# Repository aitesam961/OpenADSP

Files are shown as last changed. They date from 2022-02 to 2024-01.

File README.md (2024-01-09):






<p align="center">
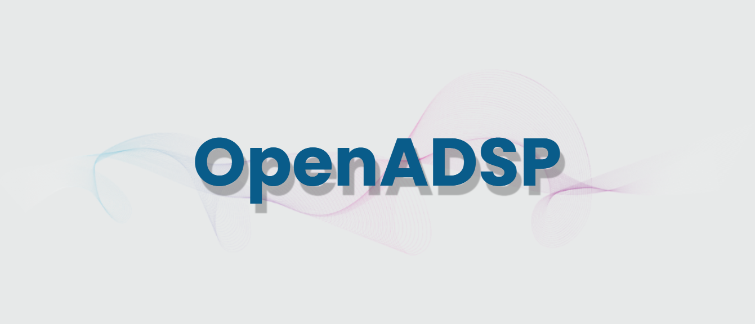
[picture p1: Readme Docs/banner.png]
  
</p>

> An Embedded solution for Digital Signal Processing Applications in Audio signal processing.

## Table of contents
* [Description](https://github.com/maitesam/OpenADSP/blob/main/README.md#Description)
* [Block Diagram](https://github.com/maitesam/OpenADSP/blob/main/README.md#block-diagram)
* [Working Explained](https://github.com/maitesam/OpenADSP/blob/main/README.md#Working-Explained)
* [Ordering Boards](https://github.com/maitesam/OpenADSP/blob/main/README.md#Ordering-Boards)
* [Assembly](https://github.com/maitesam/OpenADSP/blob/main/README.md#Assembly)
* [Flashing Firmware](https://github.com/maitesam/OpenADSP/blob/main/README.md#Flashing-Firmware)
* [Contribution](https://github.com/maitesam/OpenADSP/blob/main/README.md#Contribution)
* [License](https://github.com/maitesam/OpenADSP/blob/main/README.md#License)

## Description
This device is designed to Take data from Microphone and Process it. Later it could be sent to a wirelessly connected devices Over Bluetooth.
Aside from this, the device can stream data to host computer over USB interface.

The PCB embedds a STM32L432 MCU which is extremely capable of handling Demanding tasks such as Digital Signal Processing.
The DSP scripts could be implemented in the firmware.

## Preview 
<p align="center">
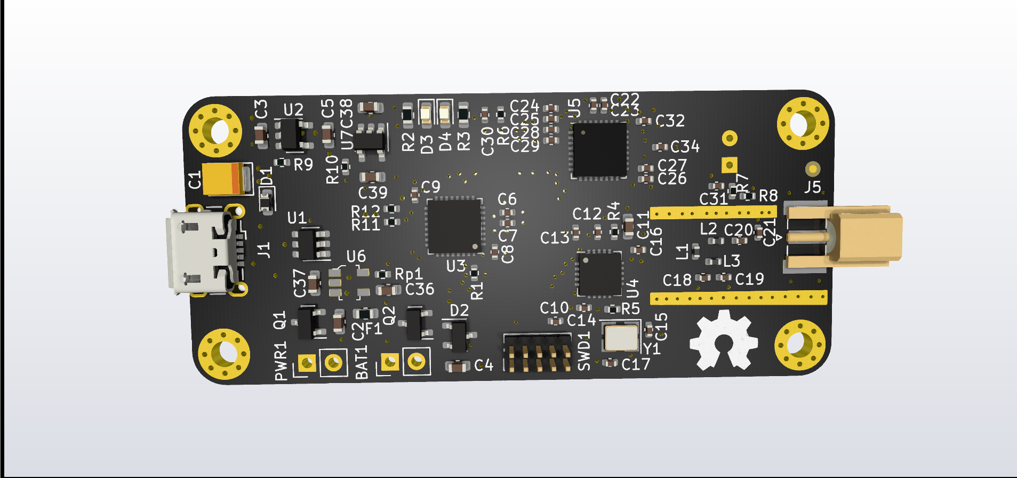
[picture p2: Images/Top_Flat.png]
  
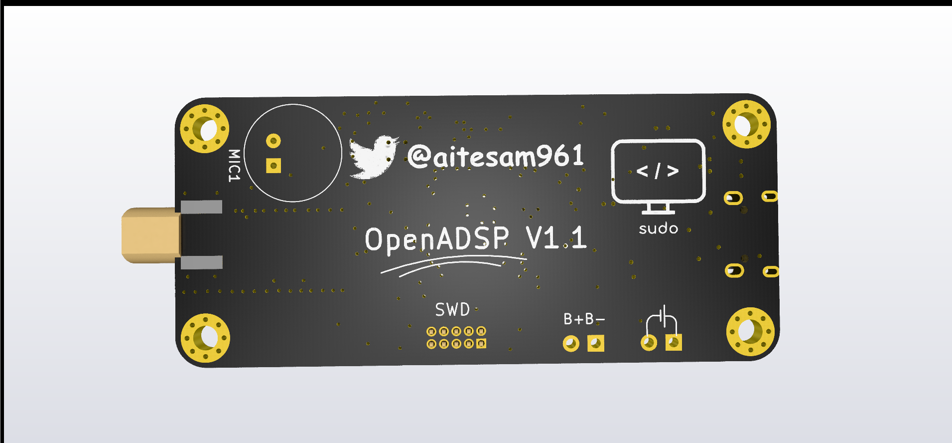
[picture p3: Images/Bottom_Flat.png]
  
</p>

## Block Diagram
The Block Diagram Illustrates the connectivity inside The Board.
<p align="center">
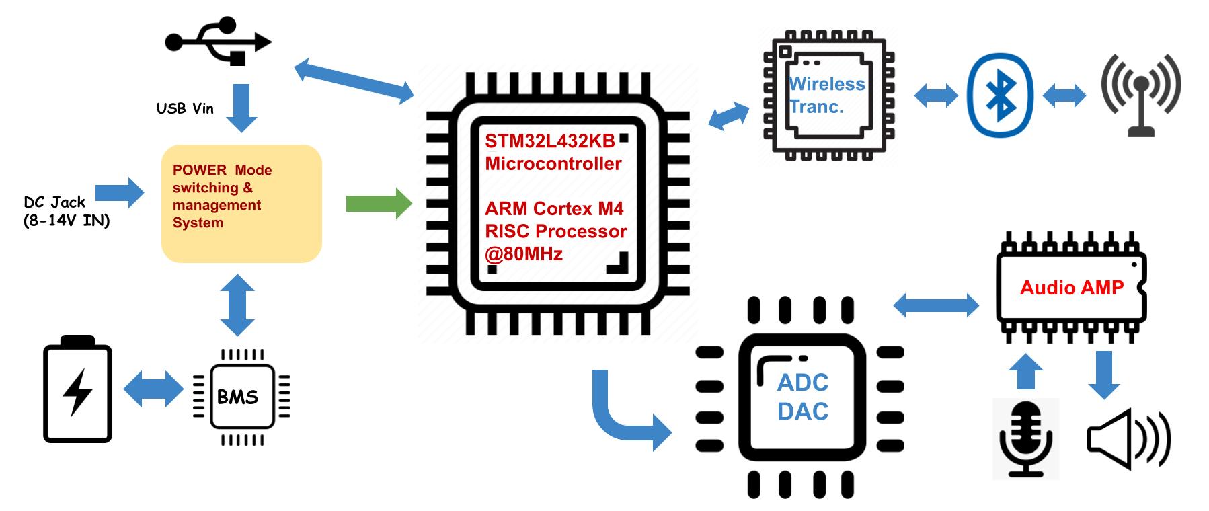
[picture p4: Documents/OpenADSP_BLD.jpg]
  
</p>

## Working Explained
This device is Designed for Digital Signal Processing applications.
The idea is to take Audio Data from a microphone, process it & Transmit to client devices.

#### What Type of Processing?
It features an STM32L432 Microcontroller with an ARM Cortex M4F (aka Black Pill). The device can be programmed to Apply Digital Filters and Effects on the audio data.
The very basic example is a Low Pass & High Pass filters.
The Incoming Audio Signal is converted to Digital (By ADC) and then Passed to STM32 which Applies programmed filters.

### Connectivity
The device is loaded with Two modes of communication.

* Bluetooth (2.4GHz)
* USB 2.0

The device is capable of Reading Data, applying filters and then Sending it wirelessly over to a Bluetooth Client
OR 
It Can be used as a USB OTG host device to send data stream over USB 2.0 Interface.

## Ordering Boards
You Can manufacture the PCBs from PCBWay.
[Check Out PCBWay](https://www.pcbway.com/setinvite.aspx?inviteid=440401)

Note: I am not affiliated with PCBWay. However, I just like their service and build quality.

## Assembly Guide
Please Refer to [Hardware Readme](https://github.com/maitesam/OpenADSP/blob/main/Hardware) for Assembly Instructions.

## Flashing Firmware
Please Refer to [Firmware Readme](https://github.com/maitesam/OpenADSP/tree/main/Firmware) to find more details about Flashing FIrmware.

### Contributions

Contributions are what make the open source community such an amazing place to learn, inspire, and create. Any contributions you make are **greatly appreciated**.

If you have a suggestion that would make this better, please fork the repo and create a pull request. You can also simply open an issue with the tag "enhancement".
Don't forget to give the project a star! Thanks again!

1. Fork the Project
2. Create your Feature Branch (`git checkout -b feature/AmazingFeature`)
3. Commit your Changes (`git commit -m 'Add some AmazingFeature'`)
4. Push to the Branch (`git push origin feature/AmazingFeature`)
5. Open a Pull Request

## Roadmap

* [x] Concept Proof
* [x] Research & Information
* [x] Finalizing The Idea
* [x] Schematics
* [x] PCB Design
* [ ] Firmware Development
* [ ] Validation & Testing
* [ ] Documentation
* [ ] Future Improvements

## File Tree

```
.
├── Datasheets
│   ├── AP2112-3.3V.pdf
│   ├── nRF24L01.pdf
│   ├── Readme.md
│   ├── SRV05-4-D.PDF
│   ├── stm32l432kb.pdf
│   └── tlv320aic3100 codec.pdf
├── Documents
│   ├── Code_Print.pdf
│   ├── ibom.html
│   ├── OpenADSP_BLD.jpg
│   ├── OpenADSP_BLD.png
│   ├── PCB Layers
│   │   ├── Audio_Processing_HW_V1.0-B_Adhesive.svg
│   │   ├── Audio_Processing_HW_V1.0-B_Cu.svg
│   │   ├── Audio_Processing_HW_V1.0-B_Mask.svg
│   │   ├── Audio_Processing_HW_V1.0-B_Paste.svg
│   │   ├── Audio_Processing_HW_V1.0-B_Silkscreen.svg
│   │   ├── Audio_Processing_HW_V1.0-Edge_Cuts.svg
│   │   ├── Audio_Processing_HW_V1.0-F_Adhesive.svg
│   │   ├── Audio_Processing_HW_V1.0-F_Cu.svg
│   │   ├── Audio_Processing_HW_V1.0-F_Mask.svg
│   │   ├── Audio_Processing_HW_V1.0-F_Paste.svg
│   │   └── Audio_Processing_HW_V1.0-F_Silkscreen.svg
│   ├── PCB_LayerWise_Export.pdf
│   └── Schematic_OpenADSP.pdf
├── Firmware
│   ├── OpenADSP Debug.launch
│   ├── OpenADSP.ioc
│   ├── Readme.md
│   ├── STM32L432KBUX_FLASH.ld
│   └── temp.html
├── Hardware
│   ├── Analog Filters.kicad_sch
│   ├── Audio_Processing_HW_V1.0.kicad_pcb
│   ├── Audio_Processing_HW_V1.0.kicad_pro
│   ├── Audio_Processing_HW_V1.0.kicad_sch
│   ├── MCU.kicad_sch
│   ├── Power & USB.kicad_sch
│   ├── Readme.md
│   ├── STM32 MCU.kicad_sch
│   ├── untitled.kicad_sch
│   ├── USB&POWER.kicad_sch
│   └── Wireless Tranceiver.kicad_sch
├── Images
│   ├── Bottom_Flat.png
│   ├── Side_Front_view.jpg
│   └── Top_Flat.png
├── LICENSE
├── Mechanical_Files
│   ├── Audio_Processing_HW_V1.0.step
│   ├── Audio_Processing_HW_V1.0.wrl
│   └── readme.txt
├── Readme Docs
│   ├── banner.png
│   ├── ezgif.com-gif-maker.gif
│   ├── icon-5974829_1280.png
│   ├── OpenADSP BOM and 6 more pages - Personal - Microsoft Edge 2022-03-02 17-06-42_Trim.mp4
│   ├── OpenADSP.jpg
│   ├── OpenADSP.png
│   └── sound-1837425_1280.png
├── README.md
└── Reference Files
    ├── an4157-stm32f3discovery-peripheral-firmware-examples-stmicroelectronics.pdf
    ├── Deleteme.html
    ├── en.MB1035-F303C-C01_Schematic.pdf
    ├── en.MB1035-F303C-D01_Schematic.pdf
    └── en.MB1035-F303C-E02_Schematic.pdf

9 directories, 59 files

```
## License

This Project is published under General Public License V3.0 See `LICENSE.txt` for more information.
> https://www.gnu.org/licenses/quick-guide-gplv3.html

<p align="right">(<a href="#top">back to top</a>)</p>

* [Jump To Start](https://github.com/maitesam/OpenADSP/blob/main/README.md#Description)

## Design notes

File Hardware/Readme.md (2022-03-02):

# Readme
## Getting started with Hardware
### Assembly Instructions
Before you start, Get the proper set of equipment.

* The Third Hand is always helpful in assembly. I recommend using some soldering Jig or Stickvise Jaws 
* Its super handy to have a cutting knife
* Better have some Non Serrated Pliers
* Obviously, A soldering Iron
* Solder Paste would be useful
* Great to have some extra Soldering Iron tips to get the perfect size

The Soldering Kit below May give you a good idea of what you need.
<p align="center">
  Material Bread logo
</p>

## General tips

 * Keep both the schematics and the board file open while you build, you'll likely want to refer back to them more often than not.
 Even I got you covered here. This [Interactive BOM](https://github.com/maitesam/OpenADSP/blob/main/Documents/ibom.html) will help you out locating the components and their references.
 Just Download the file and Open it in your Browser.
 It should present you with something like this
 
 <p align="center">
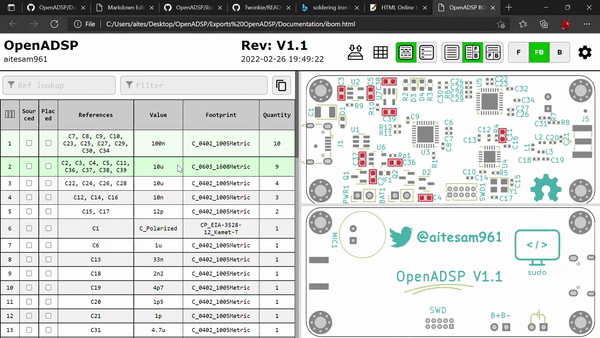
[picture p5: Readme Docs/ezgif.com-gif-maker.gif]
Material Bread logo
  
</p>

 * I wholeheartedly recommend this thread by [@thingskatedid](https://twitter.com/thingskatedid): https://twitter.com/thingskatedid/status/1348234262886039558

 * **The passives are indistinguishable once taken out of their tapes!**
   * Always work with a single value at a time
   * Only remove as many components from the tape as you need right now
   * Immediately put the tape back into the pouch it came in, as that's where the value is noted - or write the value onto the tape.

 * For each group of passives below, it saves time to batch up different types of operations: First put a small solder blob on one pad of each site, then tack down each component, then solder the other side for all components in a row.

 * If the solder joints on nearby passives blob together a lot, use some flux and a little less solder. It's also a good idea to make a final flux pass across the finished passives just like you would be drag soldering a leaded part, it makes the solder joints look a lot nicer.

### Assembly instructions

These instructions are optimized for hand assembly; the components are grouped in a way that if you follow the groups in order you should never have one component in the way of soldering another. Within a given group the order does not matter; I recommend doing all components of one value before moving on to the next value.

I found this Tutorial Video by @Electronoobs really helpful.

Alt text for your video (https://www.youtube.com/watch?v=fYInlAmPnGo)

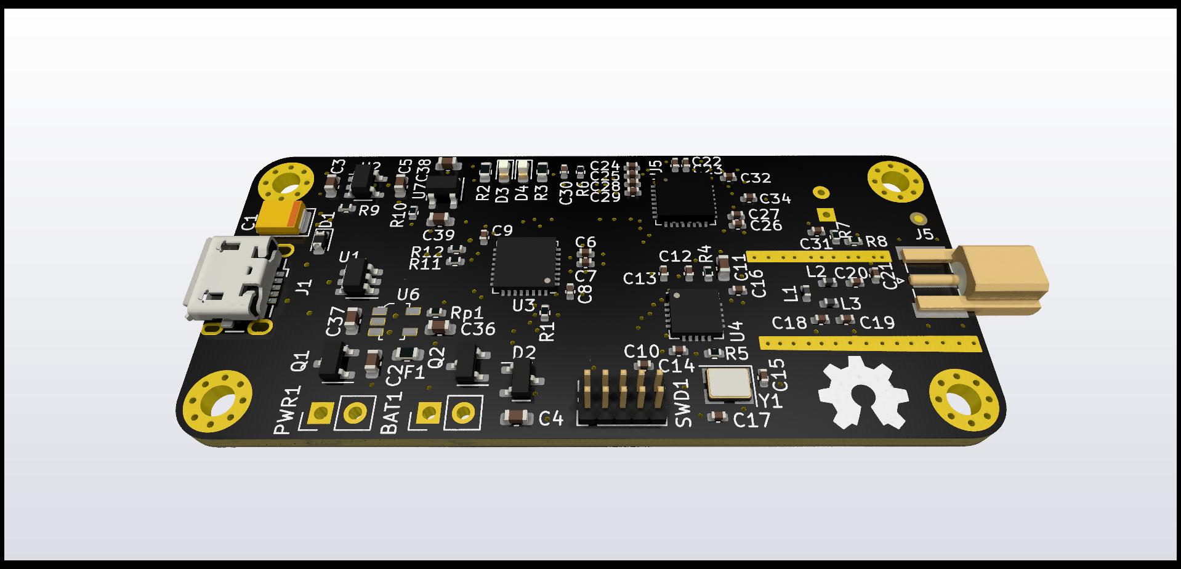
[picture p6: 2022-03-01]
Images/Side_Front_view.jpg

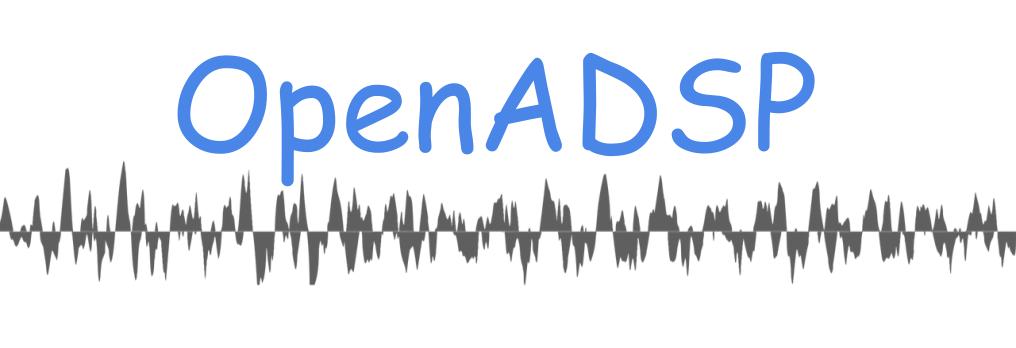
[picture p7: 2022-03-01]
Readme Docs/OpenADSP.jpg

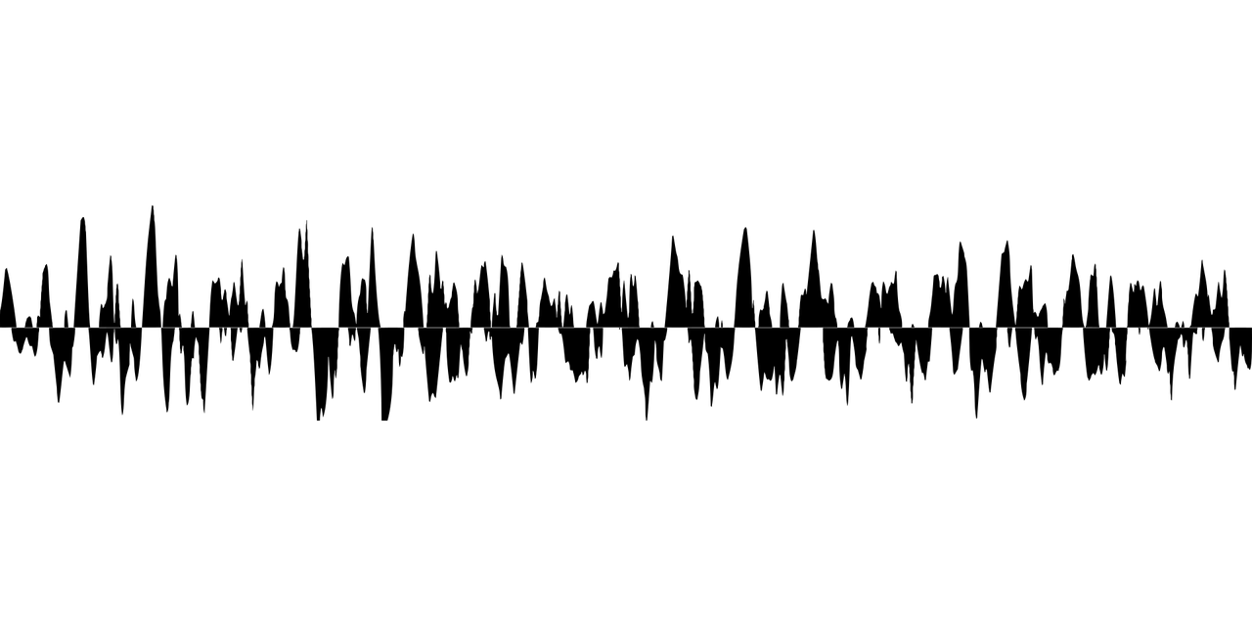
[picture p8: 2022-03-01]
Readme Docs/sound-1837425_1280.png

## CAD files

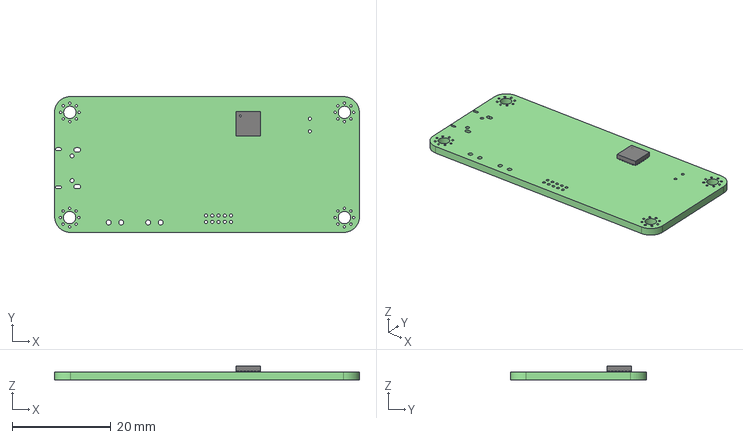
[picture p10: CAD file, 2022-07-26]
Mechanical_Files/Audio_Processing_HW_V1.0.step
61.8 x 27.5 x 2.78 mm
Audio_Processing_HW_V1.0 PCB

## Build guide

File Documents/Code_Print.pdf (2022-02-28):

main.c | Monday, February 28, 2022, 8:26 PM

1 /* USER CODE BEGIN Header */
2 /**
3 ******************************************************************************
4 | * @file | : main.c
5 | * @brief | : Main program body
6 ****************************************************************************** 7 * @attention
8 *
9 * Copyright (c) 2022 STMicroelectronics.
10 * All rights reserved.
11 *
12 * This software is licensed under terms that can be found in the LICENSE file 13 * in the root directory of this software component.
14 * If no LICENSE file comes with this software, it is provided AS-IS.
15 *
16 ****************************************************************************** 17 */
18 /* USER CODE END Header */
19 /* Includes ------------------------------------------------------------------*/ 20 #include "main.h"
21 #include "usb_device.h"
22
23 /* Private includes ----------------------------------------------------------*/ 24 /* USER CODE BEGIN Includes */
25
26 /* USER CODE END Includes */
27
28 /* Private typedef -----------------------------------------------------------*/ 29 /* USER CODE BEGIN PTD */
30
31 /* USER CODE END PTD */
32
33 /* Private define ------------------------------------------------------------*/ 34 /* USER CODE BEGIN PD */
35 /* USER CODE END PD */
36
37 /* Private macro -------------------------------------------------------------*/ 38 /* USER CODE BEGIN PM */
39
40 /* USER CODE END PM */
41
42 /* Private variables ---------------------------------------------------------*/ 43
44 I2C_HandleTypeDef hi2c1;
45 UART_HandleTypeDef huart2;
46 SMBUS_HandleTypeDef hsmbus1; 47
48 SPI_HandleTypeDef hspi1;
49
50 TIM_HandleTypeDef htim2; 51
52 /* USER CODE BEGIN PV */ 53
54 /* USER CODE END PV */
55
56 /* Private function prototypes -----------------------------------------------*/ 57 void SystemClock_Config(void);
| | Page 1

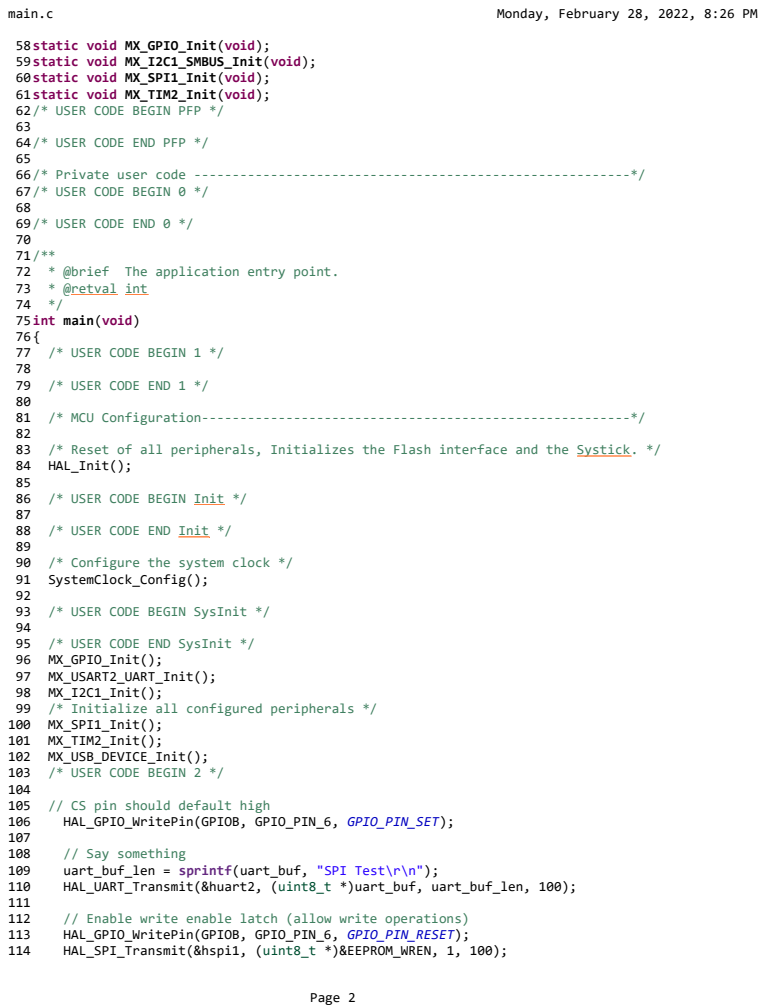
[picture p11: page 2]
main.c; Monday, February 28, 2022, 8:26 PM; Page 2

58 static void MX_GPIO_Init(void);
59 static void MX_I2C1_SMBUS_Init(void);
60 static void MX_SPI1_Init(void);
61 static void MX_TIM2_Init(void);
62 /* USER CODE BEGIN PFP */
64 /* USER CODE END PFP */
66 /* Private user code ---------------------------------------------------------*/
67 /* USER CODE BEGIN 0 */
69 /* USER CODE END 0 */
72 * @brief The application entry point.
73 * @retval int
75 int main(void)
77 /* USER CODE BEGIN 1 */
79 /* USER CODE END 1 */
81 /* MCU Configuration--------------------------------------------------------*/
83 /* Reset of all peripherals, Initializes the Flash interface and the Systick. */
84 HAL_Init();
86 /* USER CODE BEGIN Init */
88 /* USER CODE END Init */
90 /* Configure the system clock */
91 SystemClock_Config();
93 /* USER CODE BEGIN SysInit */
95 /* USER CODE END SysInit */
96 MX_GPIO_Init();
97 MX_USART2_UART_Init();
98 MX_I2C1_Init();
99 /* Initialize all configured peripherals */
100 MX_SPI1_Init();
101 MX_TIM2_Init();
102 MX_USB_DEVICE_Init();
103 /* USER CODE BEGIN 2 */
105 // CS pin should default high
106 HAL_GPIO_WritePin(GPIOB, GPIO_PIN_6, GPIO_PIN_SET);
108 // Say something
109 uart_buf_len = sprintf(uart_buf, "SPI Test\r\n");
110 HAL_UART_Transmit(&huart2, (uint8_t *)uart_buf, uart_buf_len, 100);
112 // Enable write enable latch (allow write operations)
113 HAL_GPIO_WritePin(GPIOB, GPIO_PIN_6, GPIO_PIN_RESET);
114 HAL_SPI_Transmit(&hspi1, (uint8_t *)&EEPROM_WREN, 1, 100);

main.c | Monday, February 28, 2022, 8:26 PM

115 HAL_GPIO_WritePin(GPIOB, GPIO_PIN_6, GPIO_PIN_SET);
116
117 // Read status register
118 HAL_GPIO_WritePin(GPIOB, GPIO_PIN_6, GPIO_PIN_RESET); 119 HAL_SPI_Transmit(&hspi1, (uint8_t *)&EEPROM_RDSR, 1, 100); 120 HAL_SPI_Receive(&hspi1, (uint8_t *)spi_buf, 1, 100);
121 HAL_GPIO_WritePin(GPIOB, GPIO_PIN_6, GPIO_PIN_SET);
122
123 // Print out status register
124 uart_buf_len = sprintf(uart_buf,
125 "Status: 0x x\r\n",
126 (unsigned int)spi_buf[0]);
127 HAL_UART_Transmit(&huart2, (uint8_t *)uart_buf, uart_buf_len, 100); 128
129 // Test bytes to write to EEPROM
130 spi_buf[0] = 0xAB;
131 spi_buf[1] = 0xCD;
132 spi_buf[2] = 0xEF;
133
134 // Set starting address
135 addr = 0x05;
136
137 // Write 3 bytes starting at given address
138 HAL_GPIO_WritePin(GPIOB, GPIO_PIN_6, GPIO_PIN_RESET);
139 HAL_SPI_Transmit(&hspi1, (uint8_t *)&EEPROM_WRITE, 1, 100); 140 HAL_SPI_Transmit(&hspi1, (uint8_t *)&addr, 1, 100);
141 HAL_SPI_Transmit(&hspi1, (uint8_t *)spi_buf, 3, 100);
142 HAL_GPIO_WritePin(GPIOB, GPIO_PIN_6, GPIO_PIN_SET);
143
144 // Clear buffer
145 spi_buf[0] = 0;
146 spi_buf[1] = 0;
147 spi_buf[2] = 0;
148
149 // Wait until WIP bit is cleared 150 wip = 1;
151 while (wip)
152 {
153 // Read status register
154 HAL_GPIO_WritePin(GPIOB, GPIO_PIN_6, GPIO_PIN_RESET); 155 HAL_SPI_Transmit(&hspi1, (uint8_t *)&EEPROM_RDSR, 1, 100); 156 HAL_SPI_Receive(&hspi1, (uint8_t *)spi_buf, 1, 100);
157 HAL_GPIO_WritePin(GPIOB, GPIO_PIN_6, GPIO_PIN_SET);
158
159 // Mask out WIP bit
160 wip = spi_buf[0] & 0b00000001;
161 }
162
163 // Read the 3 bytes back
164 HAL_GPIO_WritePin(GPIOB, GPIO_PIN_6, GPIO_PIN_RESET); 165 HAL_SPI_Transmit(&hspi1, (uint8_t *)&EEPROM_READ, 1, 100); 166 HAL_SPI_Transmit(&hspi1, (uint8_t *)&addr, 1, 100);
167 HAL_SPI_Receive(&hspi1, (uint8_t *)spi_buf, 3, 100);
168 HAL_GPIO_WritePin(GPIOB, GPIO_PIN_6, GPIO_PIN_SET);
169
170 // Print out bytes read
171 uart_buf_len = sprintf(uart_buf,

Page 3

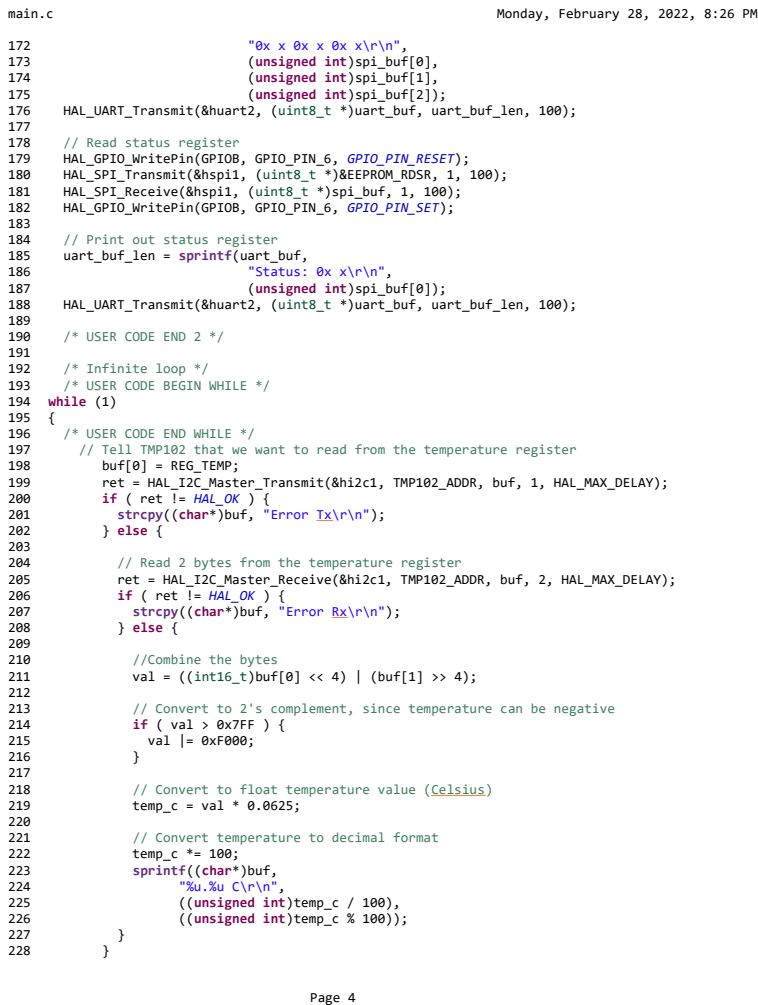
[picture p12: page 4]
main.c; Monday, February 28, 2022, 8:26 PM; Page 4

173 (unsigned int)spi_buf[0],
174 (unsigned int)spi_buf[1],
175 (unsigned int)spi_buf[2]);
176 HAL_UART_Transmit(&huart2, (uint8_t *)uart_buf, uart_buf_len, 100);
178 // Read status register
179 HAL_GPIO_WritePin(GPIOB, GPIO_PIN_6, GPIO_PIN_RESET);
180 HAL_SPI_Transmit(&hspi1, (uint8_t *)&EEPROM_RDSR, 1, 100);
181 HAL_SPI_Receive(&hspi1, (uint8_t *)spi_buf, 1, 100);
182 HAL_GPIO_WritePin(GPIOB, GPIO_PIN_6, GPIO_PIN_SET);
184 // Print out status register
185 uart_buf_len = sprintf(uart_buf,
186 "Status: 0x x\r\n",
187 (unsigned int)spi_buf[0]);
188 HAL_UART_Transmit(&huart2, (uint8_t *)uart_buf, uart_buf_len, 100);
190 /* USER CODE END 2 */
192 /* Infinite loop */
193 /* USER CODE BEGIN WHILE */
194 while (1)
196 /* USER CODE END WHILE */
197 // Tell TMP102 that we want to read from the temperature register
198 buf[0] = REG_TEMP;
199 ret = HAL_I2C_Master_Transmit(&hi2c1, TMP102_ADDR, buf, 1, HAL_MAX_DELAY);
200 if ( ret != HAL_OK ) {
201 strcpy((char*)buf, "Error Tx\r\n");
202 } else {
204 // Read 2 bytes from the temperature register
205 ret = HAL_I2C_Master_Receive(&hi2c1, TMP102_ADDR, buf, 2, HAL_MAX_DELAY);
206 if ( ret != HAL_OK ) {
207 strcpy((char*)buf, "Error Rx\r\n");
208 } else {
210 //Combine the bytes
211 val = ((int16_t)buf[0] << 4) | (buf[1] >> 4);
213 // Convert to 2's complement, since temperature can be negative
214 if ( val > 0x7FF ) {
215 val |= 0xF000;
218 // Convert to float temperature value (Celsius)
219 temp_c = val * 0.0625;
221 // Convert temperature to decimal format
222 temp_c *= 100;
223 sprintf((char*)buf,
225 ((unsigned int)temp_c / 100),
226 ((unsigned int)temp_c % 100));

main.c | Monday, February 28, 2022, 8:26 PM

229
230 // Send out buffer (temperature or error message)
231 HAL_UART_Transmit(&huart2, buf, strlen((char*)buf), HAL_MAX_DELAY);
232
233 // Wait
234 HAL_Delay(500);
235
236 /* USER CODE END WHILE */ 237
238 /* USER CODE BEGIN 3 */ 239 }
240 /* USER CODE END 3 */
241 /*USER CODE END 3 */
242 }
243
244 /**
245 * @brief System Clock Configuration 246 * @retval None
247 */
248 void SystemClock_Config(void)
249 {
250 RCC_OscInitTypeDef RCC_OscInitStruct = {0};
251 RCC_ClkInitTypeDef RCC_ClkInitStruct = {0};
252
253 /** Configure the main internal regulator output voltage
254 */
255 if (HAL_PWREx_ControlVoltageScaling(PWR_REGULATOR_VOLTAGE_SCALE1) != HAL_OK) 256 {
257 Error_Handler();
258 }
259 /** Initializes the RCC Oscillators according to the specified parameters 260 * in the RCC_OscInitTypeDef structure.
261 */
262 RCC_OscInitStruct.OscillatorType = RCC_OSCILLATORTYPE_HSE;
263 RCC_OscInitStruct.HSEState = RCC_HSE_BYPASS;
264 RCC_OscInitStruct.PLL.PLLState = RCC_PLL_NONE;
265 if (HAL_RCC_OscConfig(&RCC_OscInitStruct) != HAL_OK)
266 {
267 Error_Handler();
268 }
269 /** Initializes the CPU, AHB and APB buses clocks
270 */
271 RCC_ClkInitStruct.ClockType = RCC_CLOCKTYPE_HCLK|RCC_CLOCKTYPE_SYSCLK 272 |RCC_CLOCKTYPE_PCLK1|RCC_CLOCKTYPE_PCLK2; 273 RCC_ClkInitStruct.SYSCLKSource = RCC_SYSCLKSOURCE_HSE;
274 RCC_ClkInitStruct.AHBCLKDivider = RCC_SYSCLK_DIV1;
275 RCC_ClkInitStruct.APB1CLKDivider = RCC_HCLK_DIV1;
276 RCC_ClkInitStruct.APB2CLKDivider = RCC_HCLK_DIV1;
277
278 if (HAL_RCC_ClockConfig(&RCC_ClkInitStruct, FLASH_LATENCY_0) != HAL_OK) 279 {
280 Error_Handler();
281 }
282 }
283
284 /**
285 * @brief I2C1 Initialization Function

Page 5

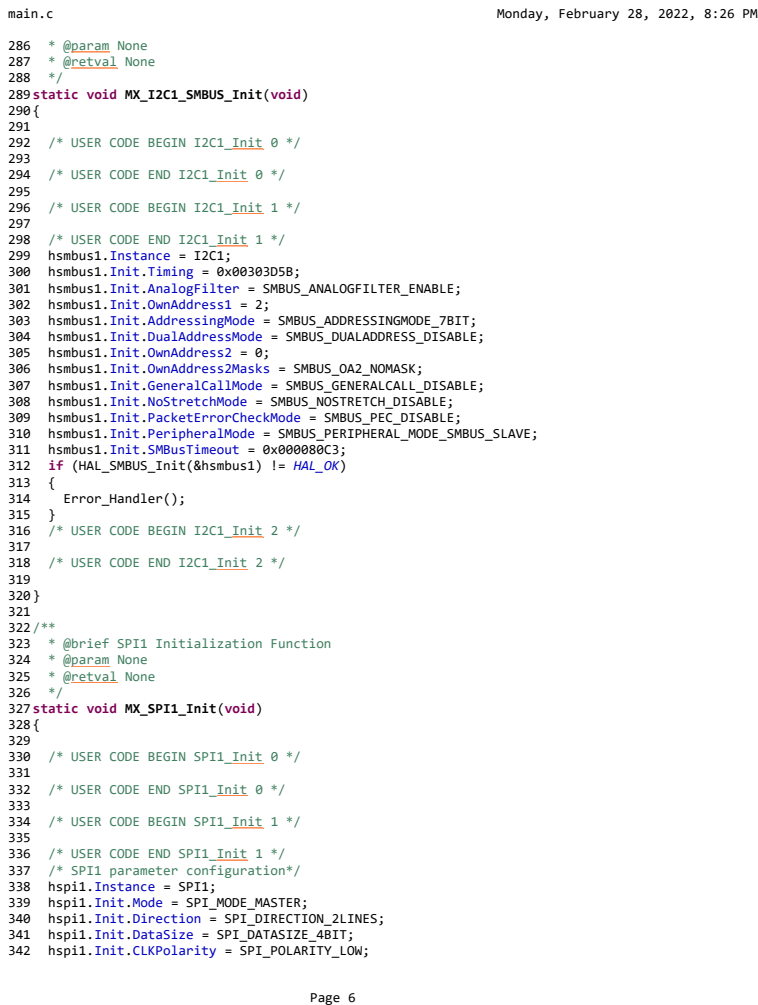
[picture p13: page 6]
main.c; Monday, February 28, 2022, 8:26 PM; 286 * @param None 287 * @retval None 288 */ 289 static void MX_I2C1_SMBUS_Init(void) 290 { 291 292 /* USER CODE BEGIN I2C1_Init 0 */ 293 294 /* USER CODE END I2C1_Init 0 */ 295 296 /* USER CODE BEGIN I2C1_Init 1 */ 297 298 /* USER CODE END I2C1_Init 1 */ 299 hsmbus1.Instance = I2C1; 300 hsmbus1.Init.Timing = 0x00303D5B; 301 hsmbus1.Init.AnalogFilter = SMBUS_ANALOGFILTER_ENABLE; 302 hsmbus1.Init.OwnAddress1 = 2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

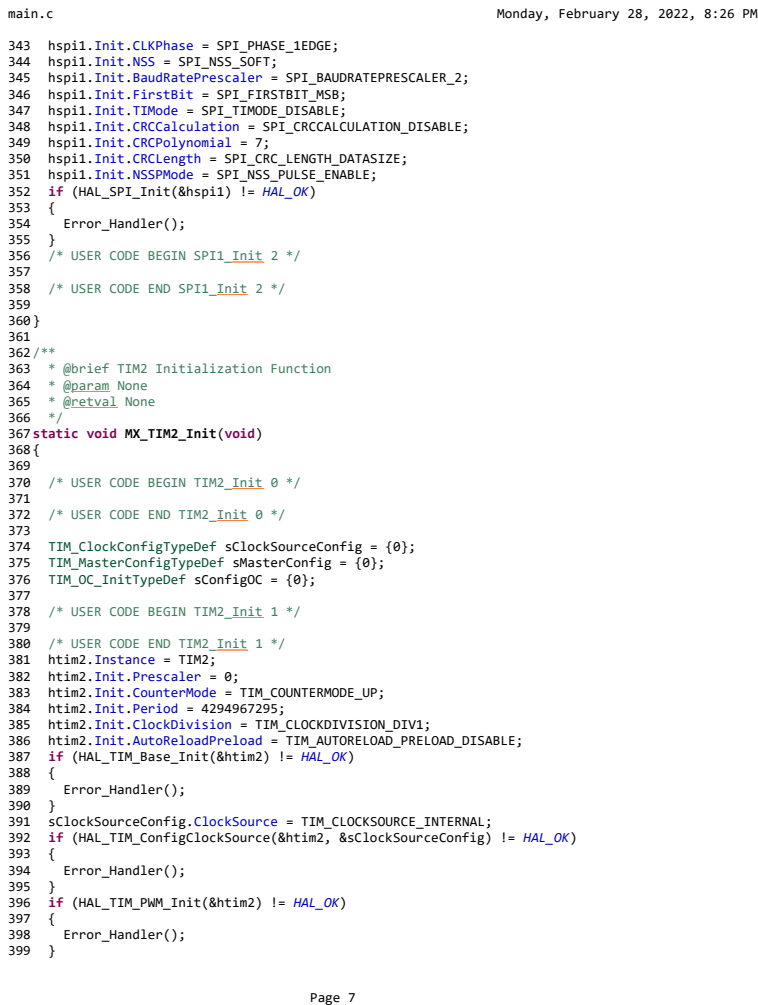
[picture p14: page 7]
main.c; Monday, February 28, 2022, 8:26 PM; 343 hspi1.Init.CLKPhase = SPI_PHASE_1EDGE; 344 hspi1.Init.NSS = SPI_NSS_SOFT; 345 hspi1.Init.BaudRatePrescaler = SPI_BAUDRATEPRESCALER_2; 346 hspi1.Init.FirstBit = SPI_FIRSTBIT_MSB; 347 hspi1.Init.TIMode = SPI_TIMODE_DISABLE; 348 hspi1.Init.CRCCalculation = SPI_CRCCALCULATION_DISABLE; 349 hspi1.Init.CRCPolynomial = 7; 350 hspi1.Init.CRCLength = SPI_CRC_LENGTH_DATASIZE; 351 hspi1.Init.NSSPMode = SPI_NSS_PULSE_ENABLE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

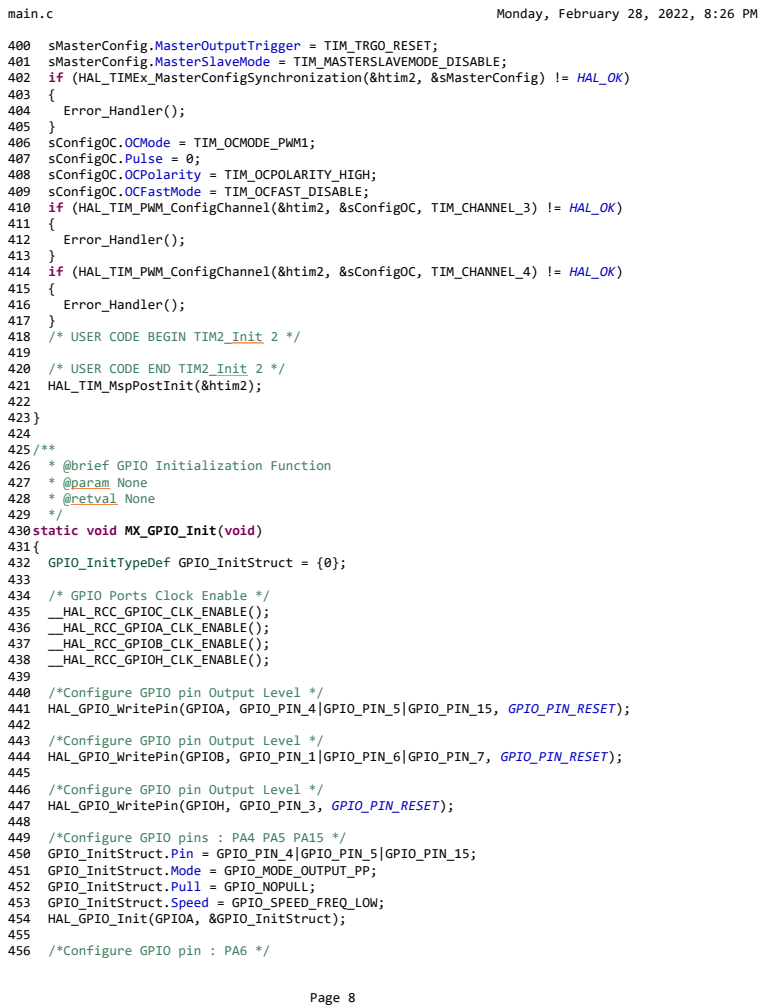
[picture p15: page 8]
main.c; Monday, February 28, 2022, 8:26 PM; 400 sMasterConfig.MasterOutputTrigger = TIM_TRGO_RESET; 401 sMasterConfig.MasterSlaveMode = TIM_MASTERSLAVEMODE_DISABLE; 402 if (HAL_TIMEx_MasterConfigSynchronization(&htim2, &sMasterConfig) != HAL_OK) 403 { 404 Error_Handler(); 405 } 406 sConfigOC.OCMode = TIM_OCMODE_PWM1; 407 sConfigOC.Pulse = 0; 408 sConfigOC.OCPolarity = TIM_OCPOLARITY_HIGH; 409 sConfigOC.OCFastMode = TIM_OCFAST_DISABLE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

main.c | Monday, February 28, 2022, 8:26 PM

457 GPIO_InitStruct.Pin = GPIO_PIN_6;
458 GPIO_InitStruct.Mode = GPIO_MODE_INPUT;
459 GPIO_InitStruct.Pull = GPIO_NOPULL;
460 HAL_GPIO_Init(GPIOA, &GPIO_InitStruct);
461
462 /*Configure GPIO pins : PB1 PB6 PB7 */
463 GPIO_InitStruct.Pin = GPIO_PIN_1|GPIO_PIN_6|GPIO_PIN_7; 464 GPIO_InitStruct.Mode = GPIO_MODE_OUTPUT_PP;
465 GPIO_InitStruct.Pull = GPIO_NOPULL;
466 GPIO_InitStruct.Speed = GPIO_SPEED_FREQ_LOW;
467 HAL_GPIO_Init(GPIOB, &GPIO_InitStruct); 468
469 /*Configure GPIO pin : PH3 */
470 GPIO_InitStruct.Pin = GPIO_PIN_3;
471 GPIO_InitStruct.Mode = GPIO_MODE_OUTPUT_PP; 472 GPIO_InitStruct.Pull = GPIO_NOPULL;
473 GPIO_InitStruct.Speed = GPIO_SPEED_FREQ_LOW; 474 HAL_GPIO_Init(GPIOH, &GPIO_InitStruct); 475
476 }
477
478 /* USER CODE BEGIN 4 */ 479
480 /* USER CODE END 4 */
481
482 /**
483 * @brief This function is executed in case of error occurrence. 484 * @retval None
485 */
486 void Error_Handler(void)
487 {
488 /* USER CODE BEGIN Error_Handler_Debug */
489 /* User can add his own implementation to report the HAL error return state */ 490 __disable_irq();
491 while (1)
492 {
493 }
494 /* USER CODE END Error_Handler_Debug */ 495 }
496
497 #ifdef USE_FULL_ASSERT
498 /**
499 * @brief Reports the name of the source file and the source line number
500 * | where the assert_param error has occurred.
501 * @param file: pointer to the source file name
502 * @param line: assert_param error line source number
503 * @retval None
504 */
505 void assert_failed(uint8_t *file, uint32_t line)
506 {
507 /* USER CODE BEGIN 6 */
508 /* User can add his own implementation to report the file name and line number, 509 ex: printf("Wrong parameters value: file %s on line %d\r\n", file, line) */ 510 /* USER CODE END 6 */
511 }
512 #endif /* USE_FULL_ASSERT */
513
| Page 9

main.c | Monday, February 28, 2022, 8:26 PM

514

Page 10

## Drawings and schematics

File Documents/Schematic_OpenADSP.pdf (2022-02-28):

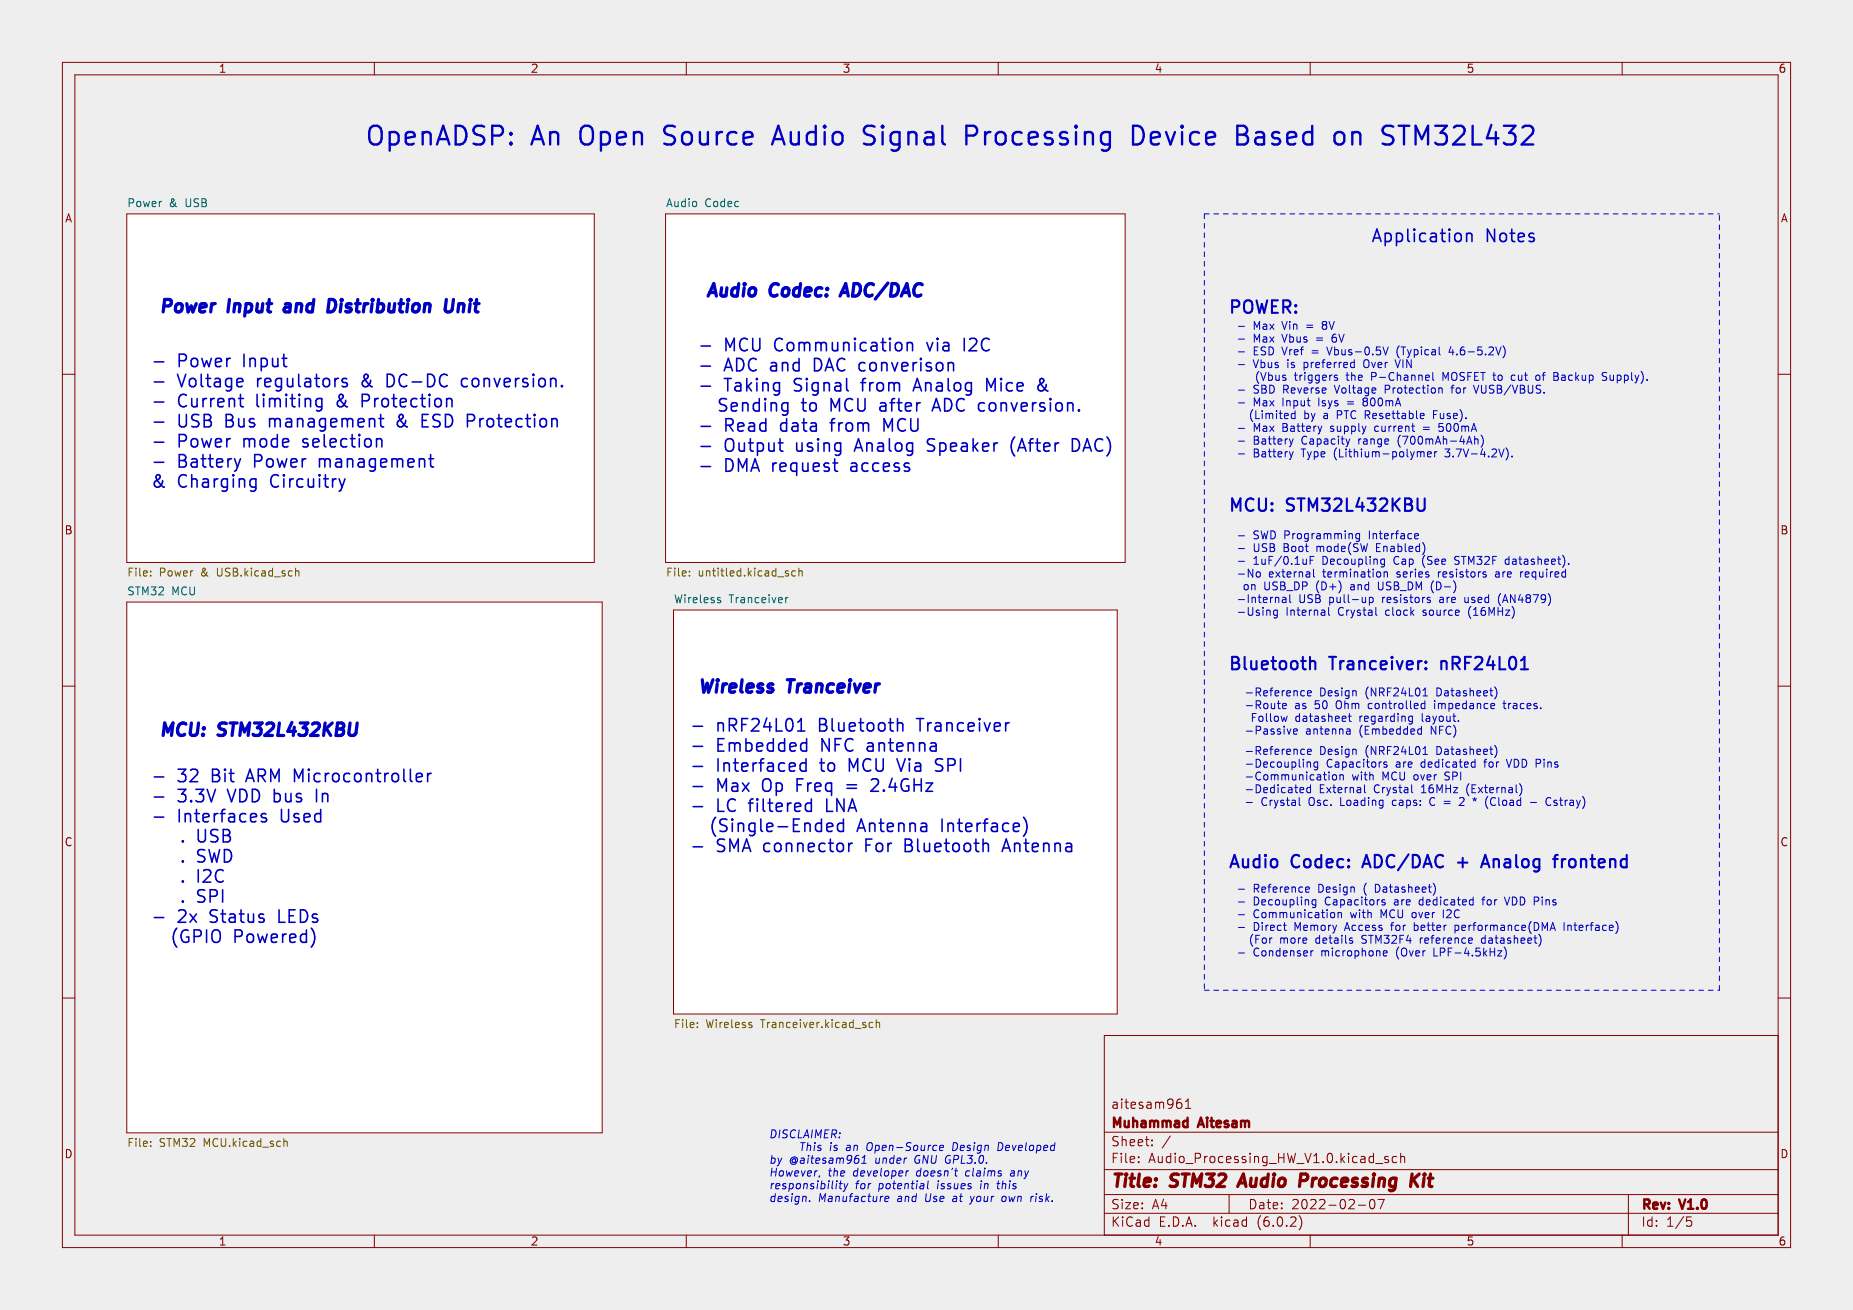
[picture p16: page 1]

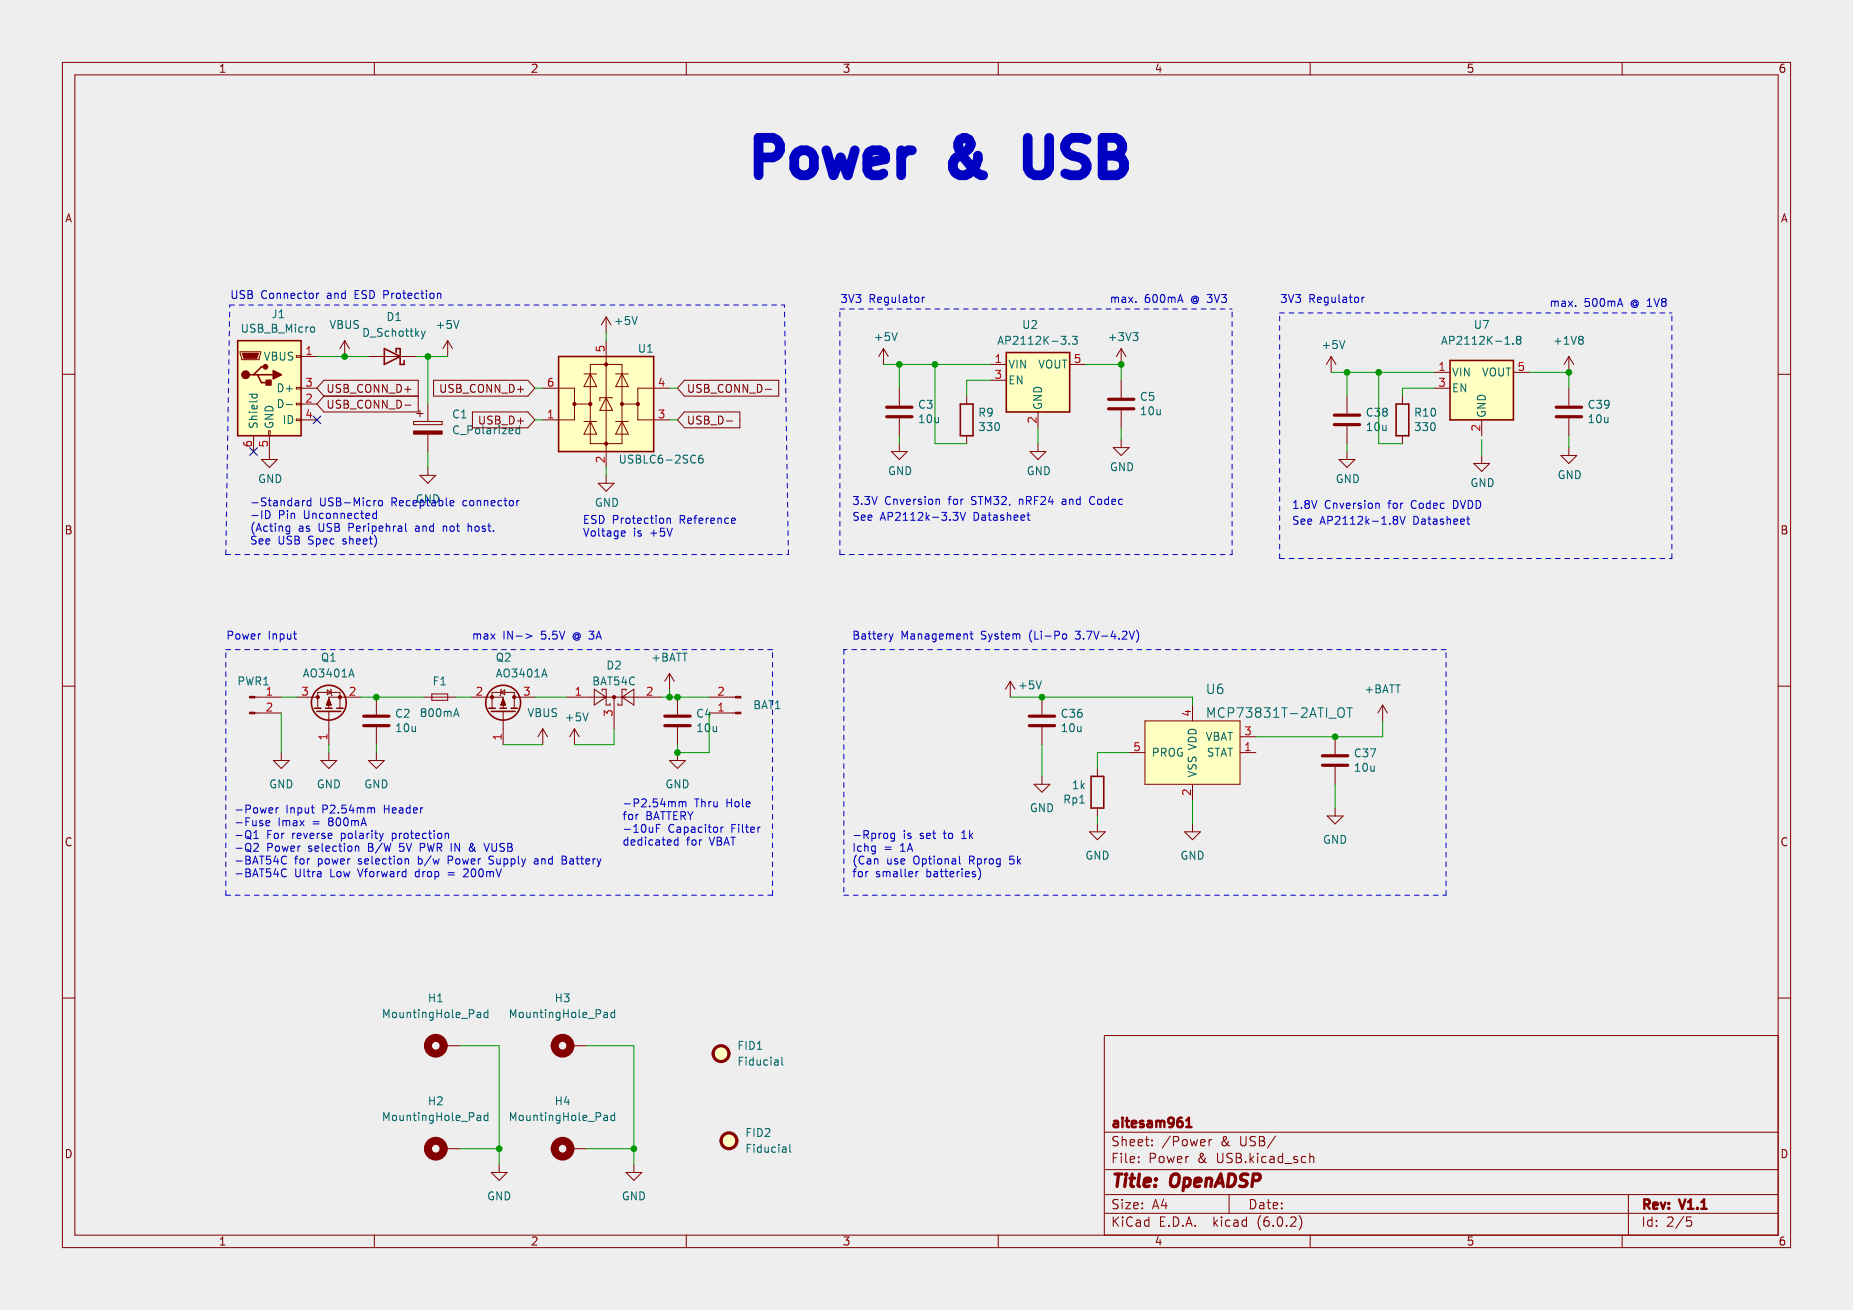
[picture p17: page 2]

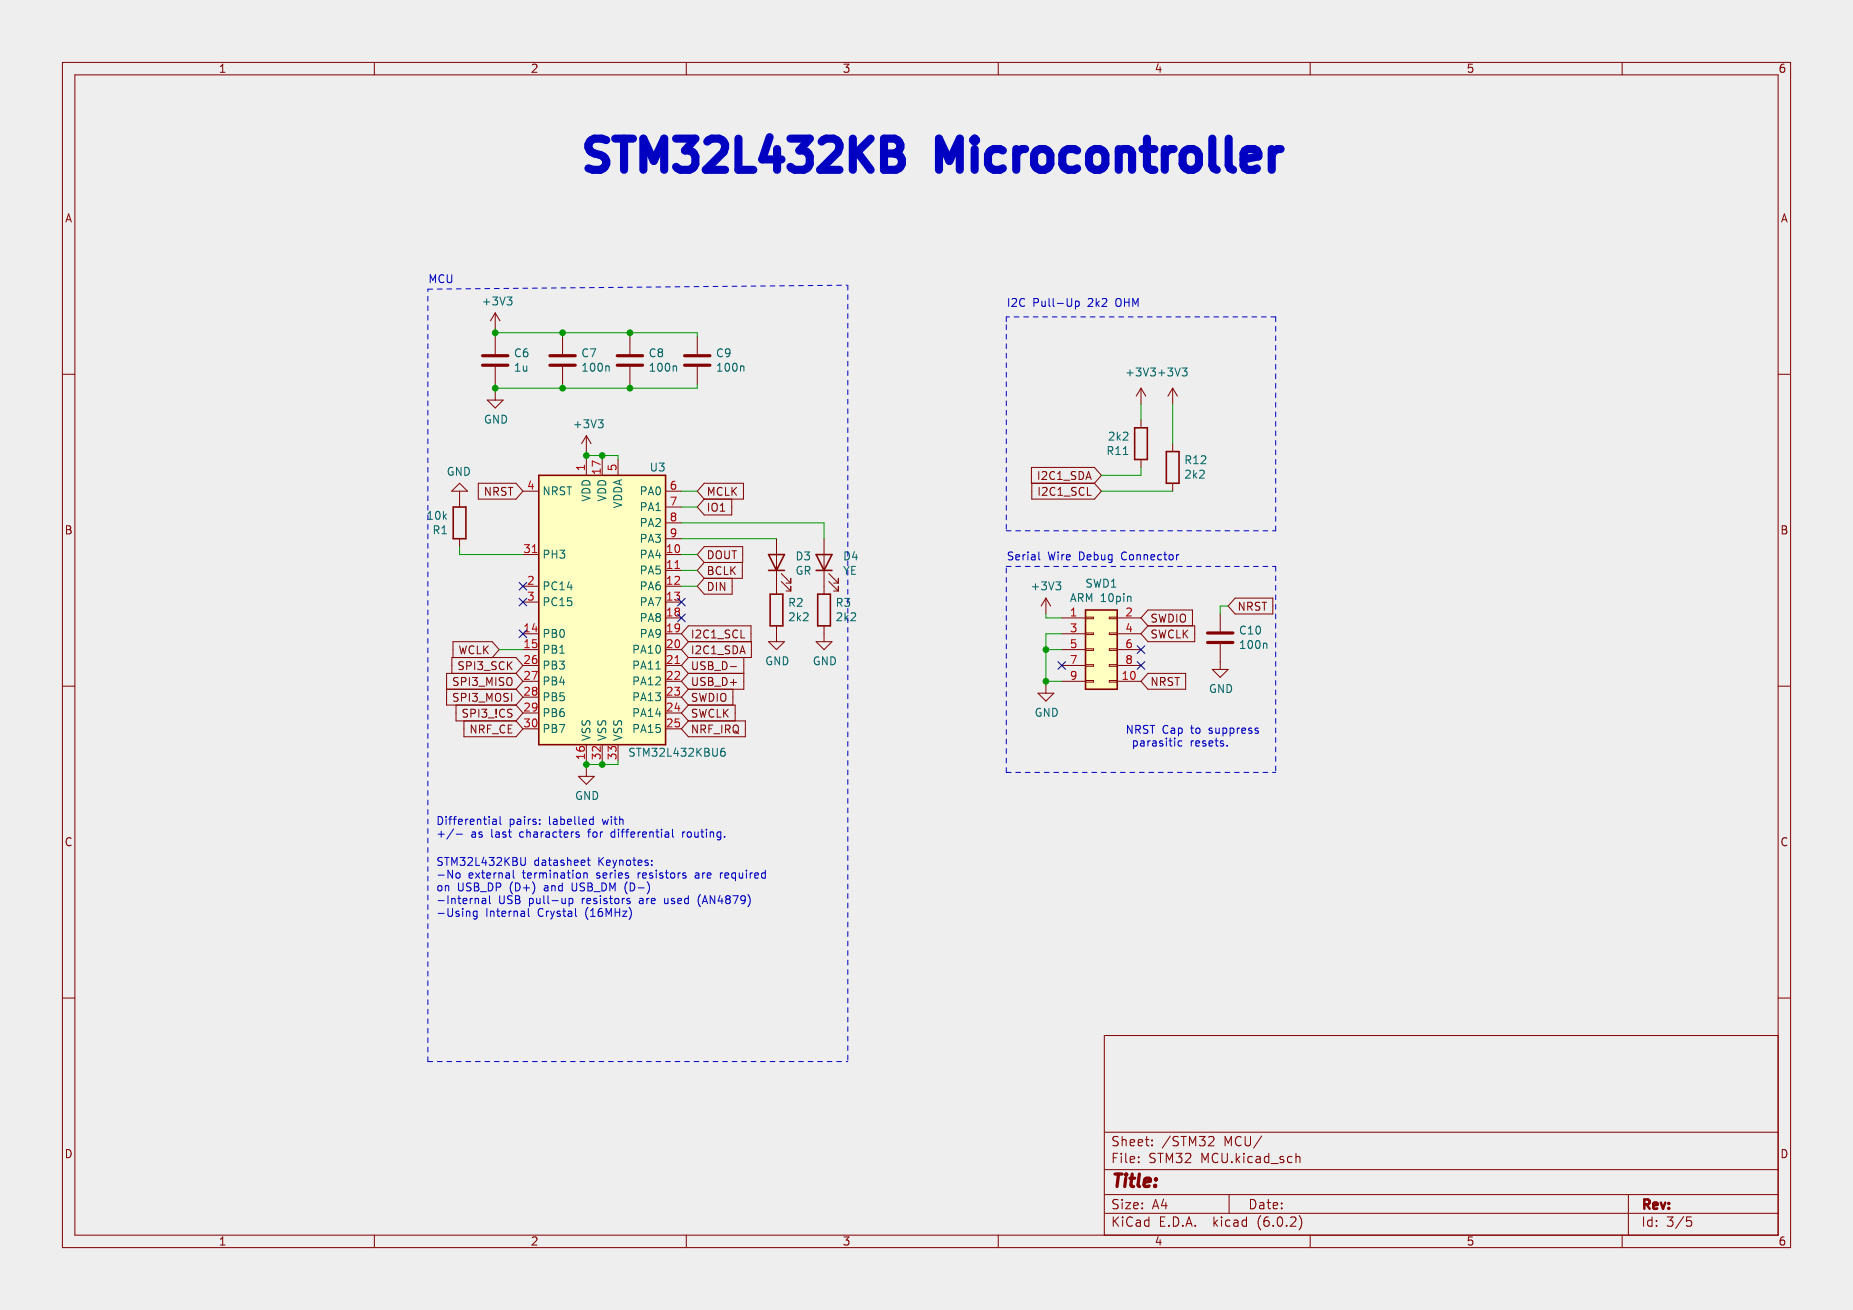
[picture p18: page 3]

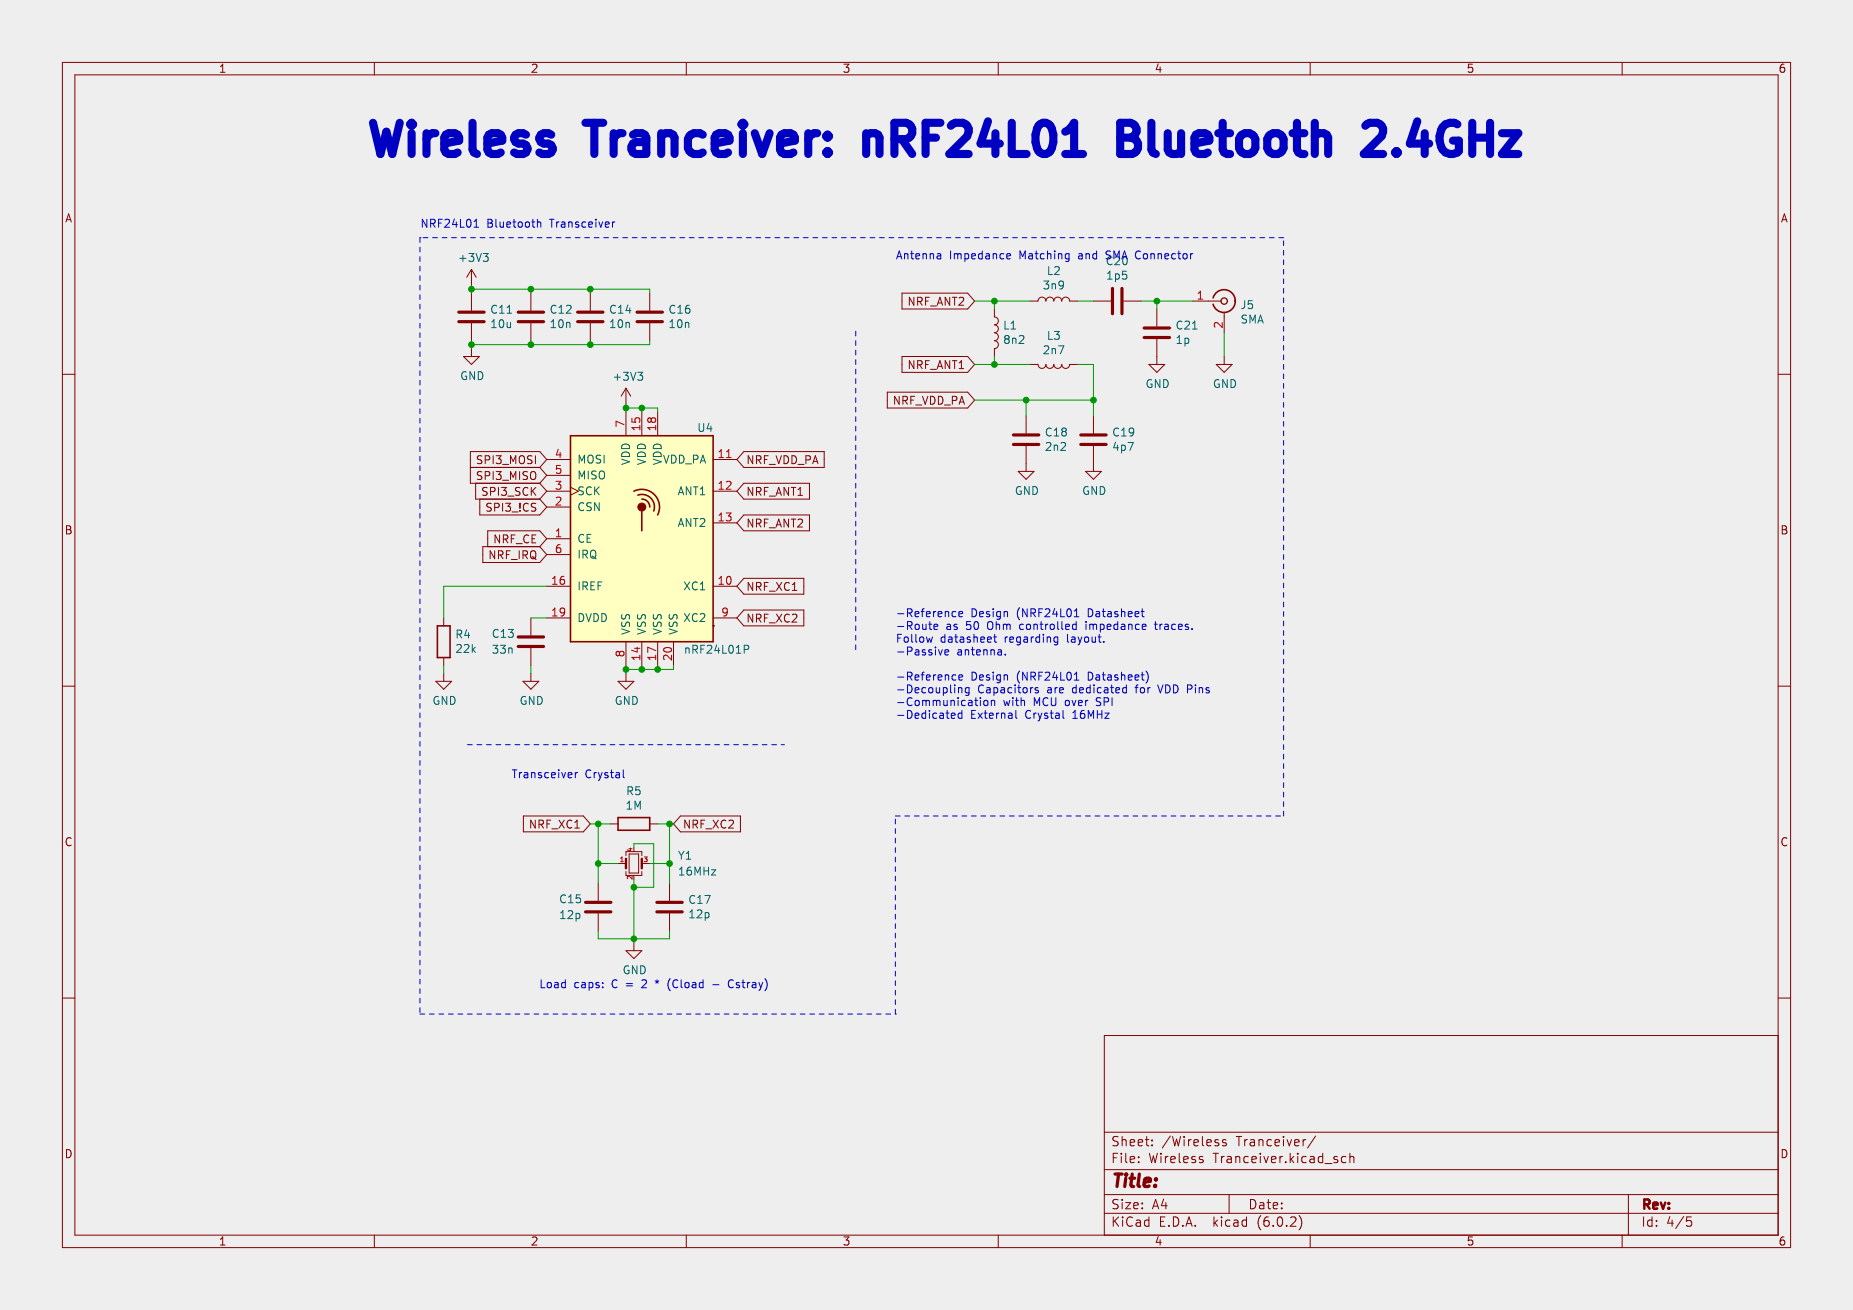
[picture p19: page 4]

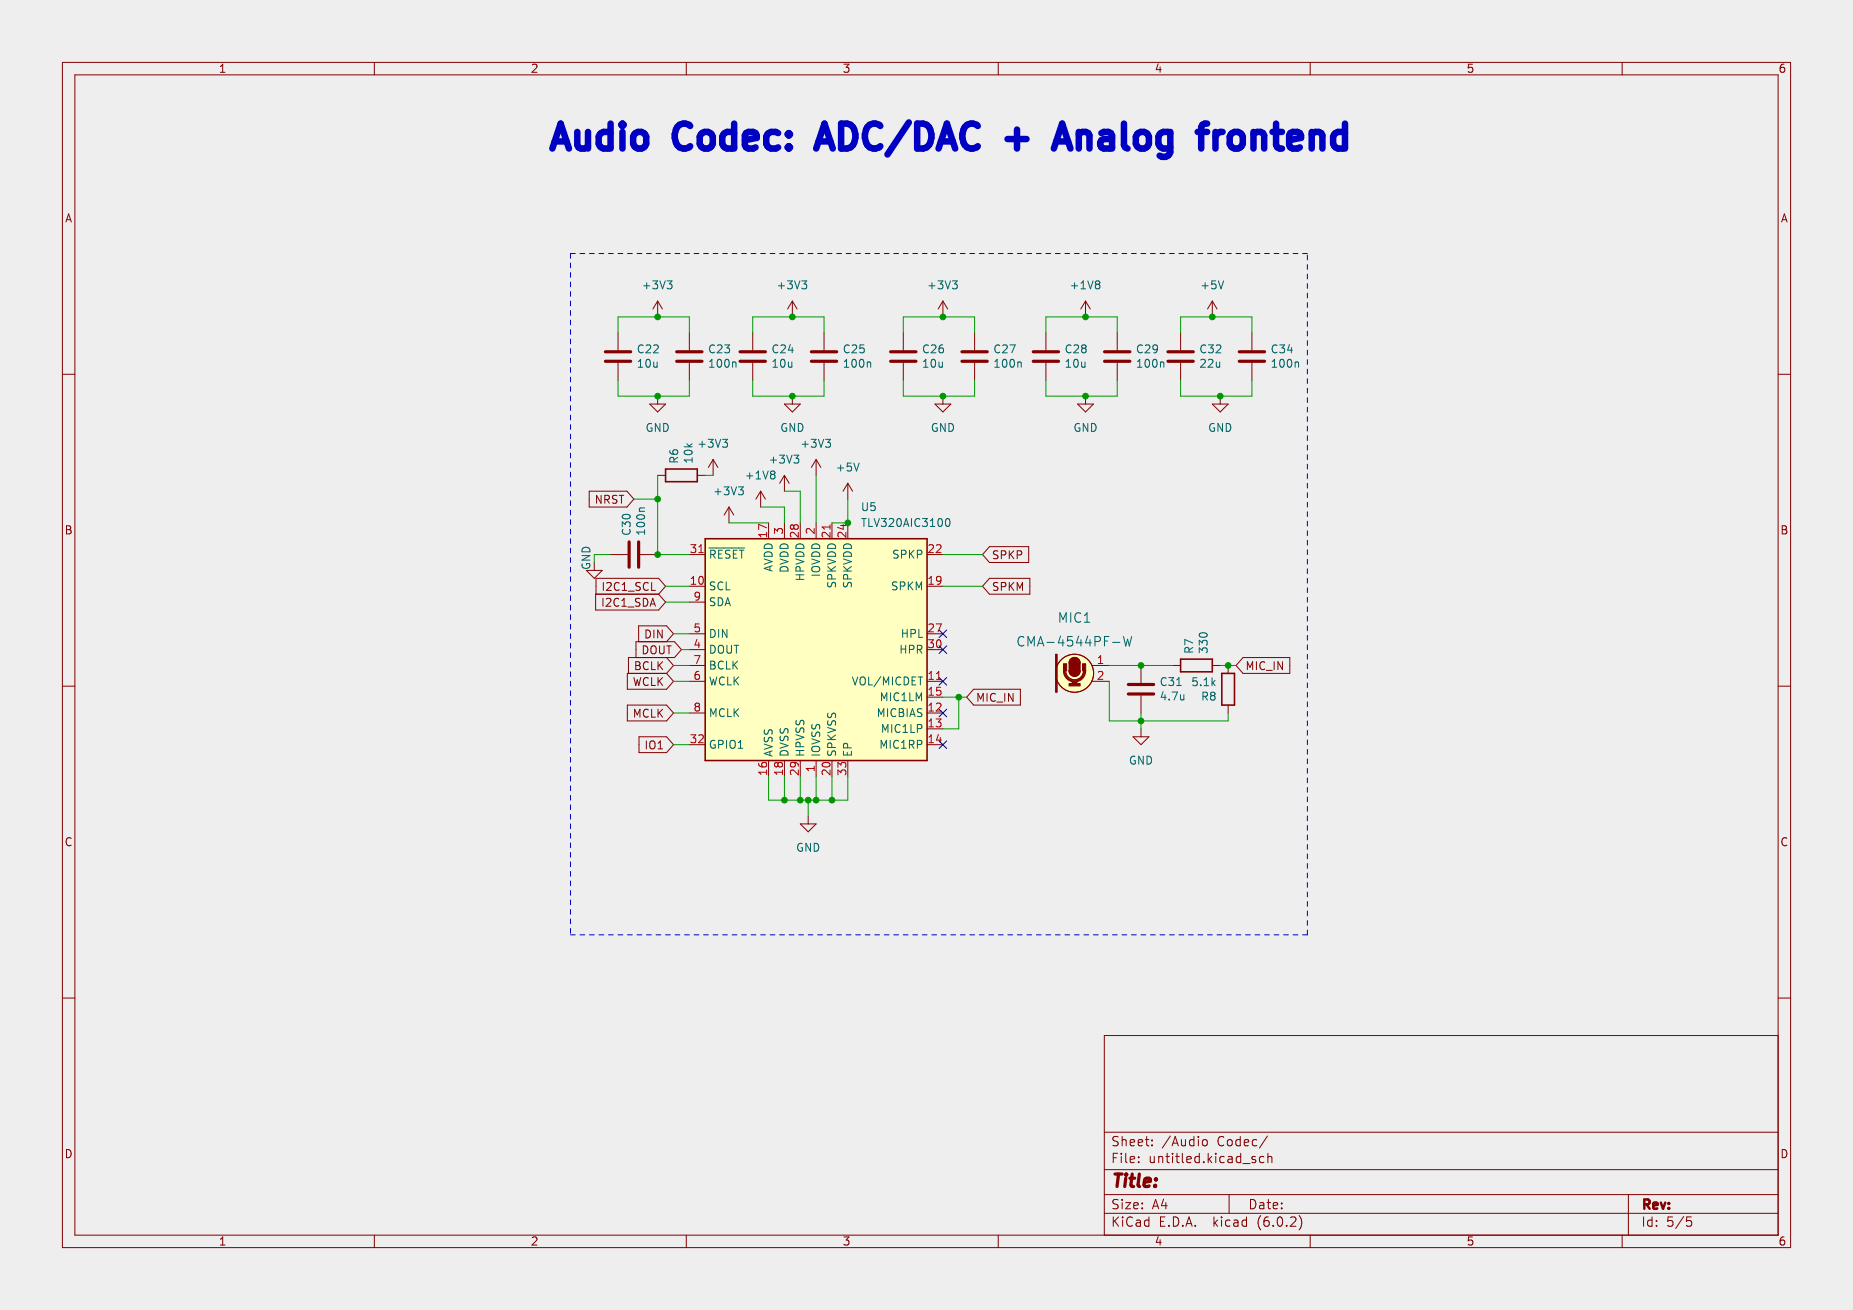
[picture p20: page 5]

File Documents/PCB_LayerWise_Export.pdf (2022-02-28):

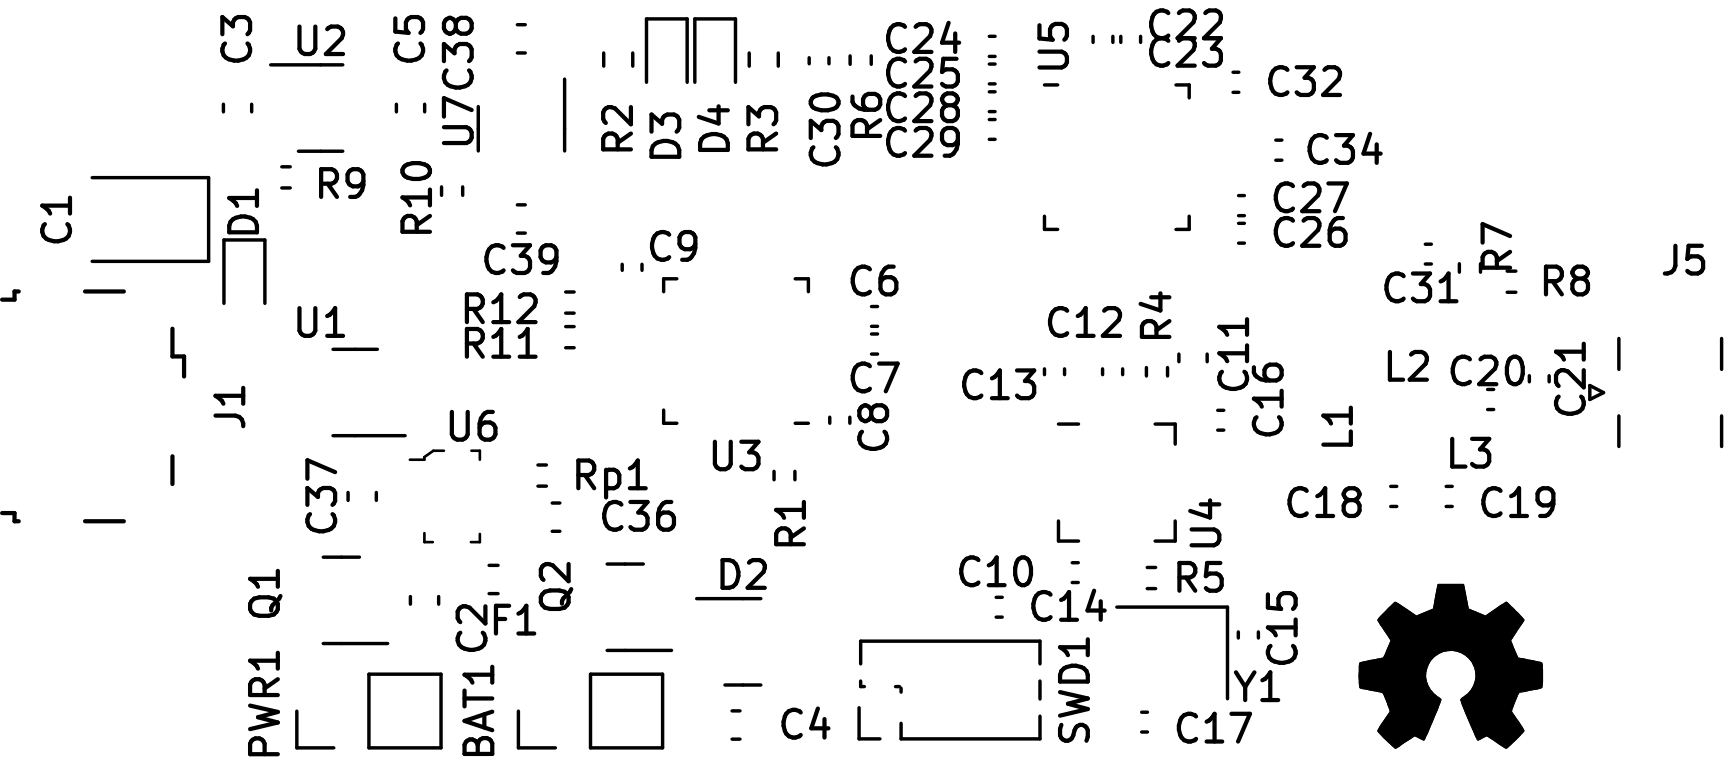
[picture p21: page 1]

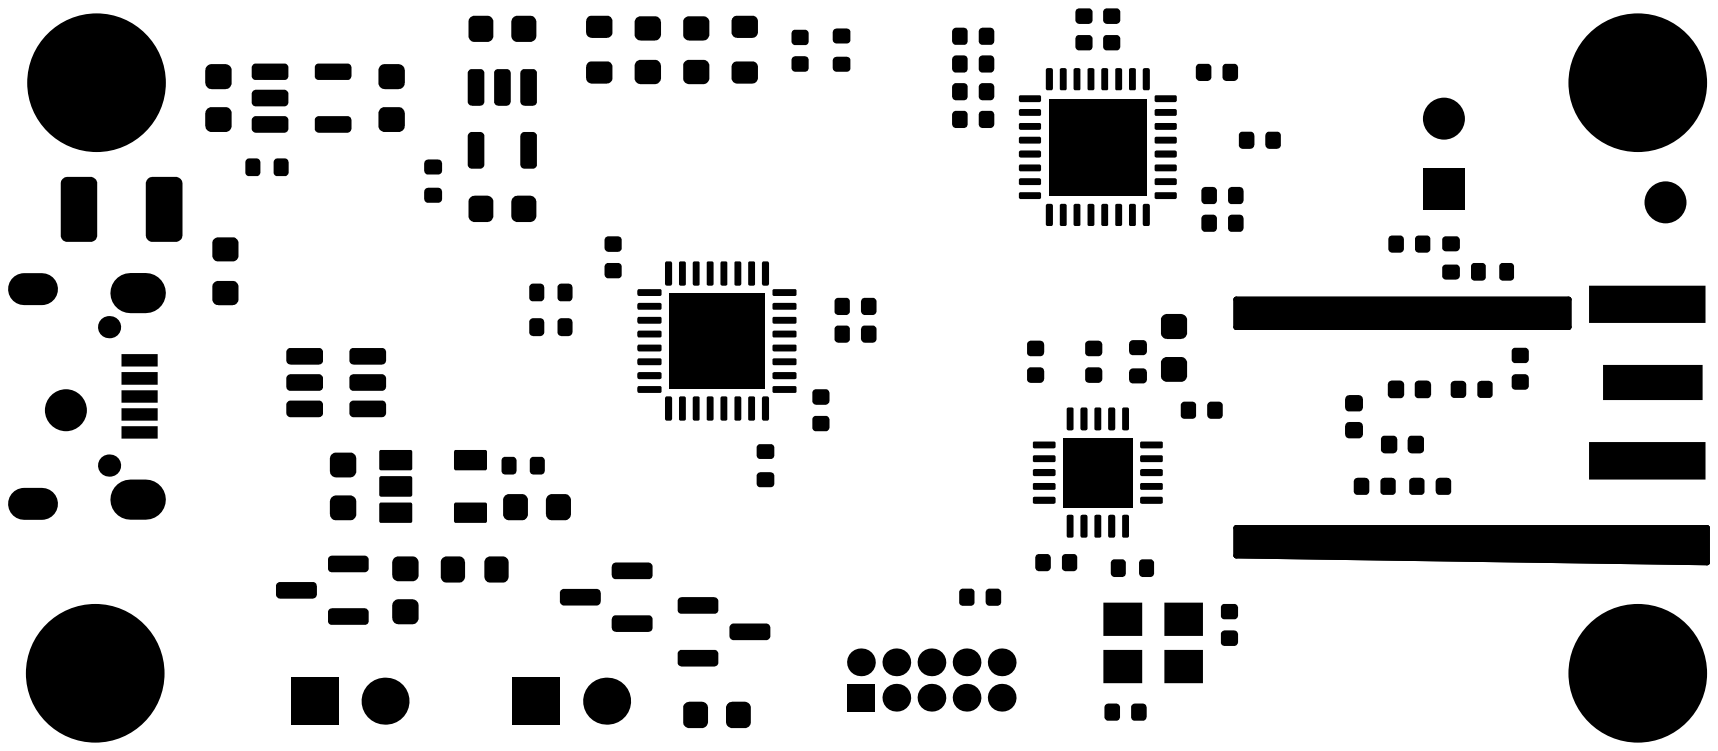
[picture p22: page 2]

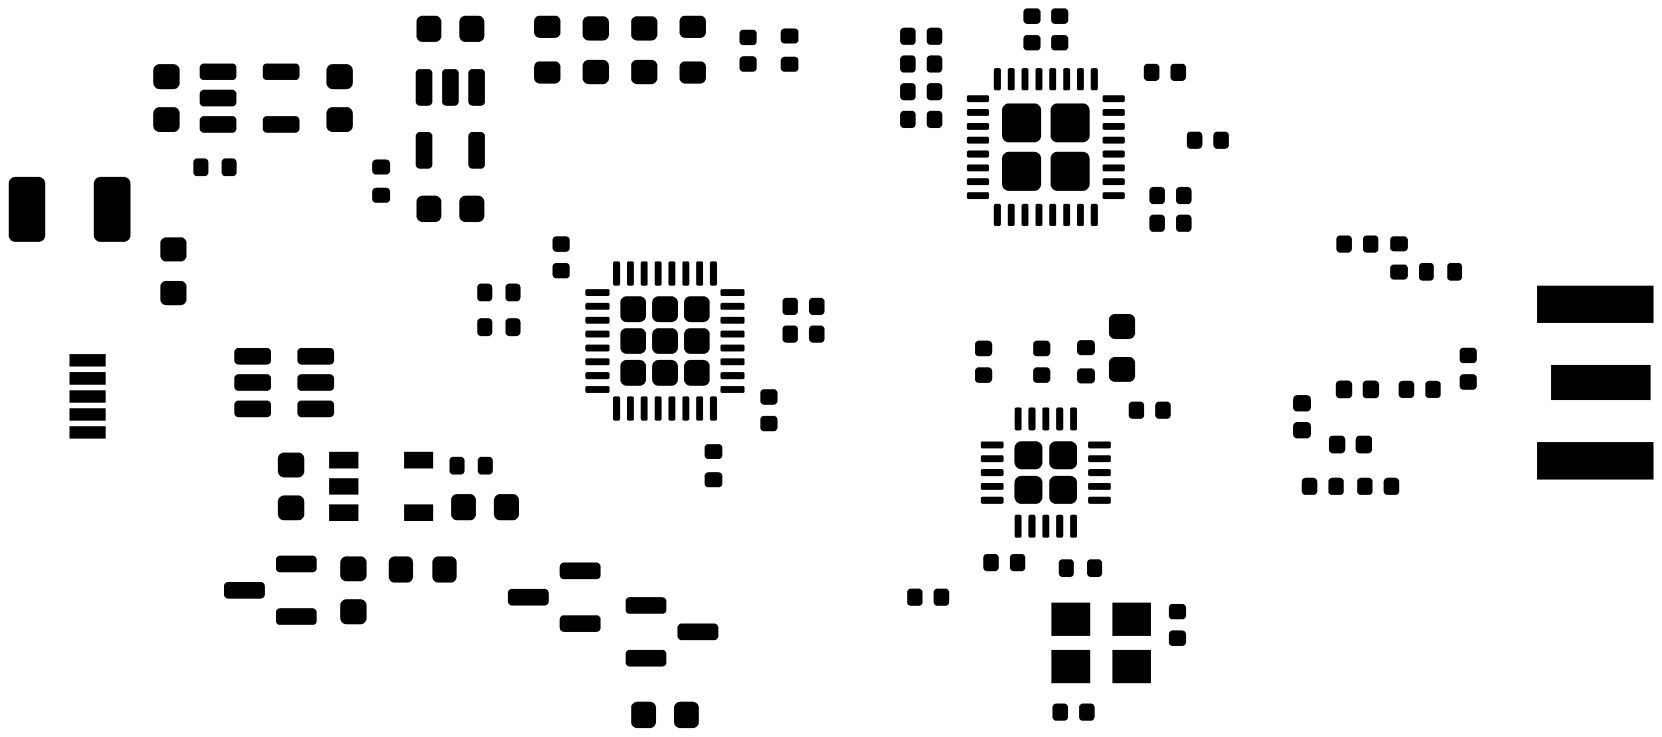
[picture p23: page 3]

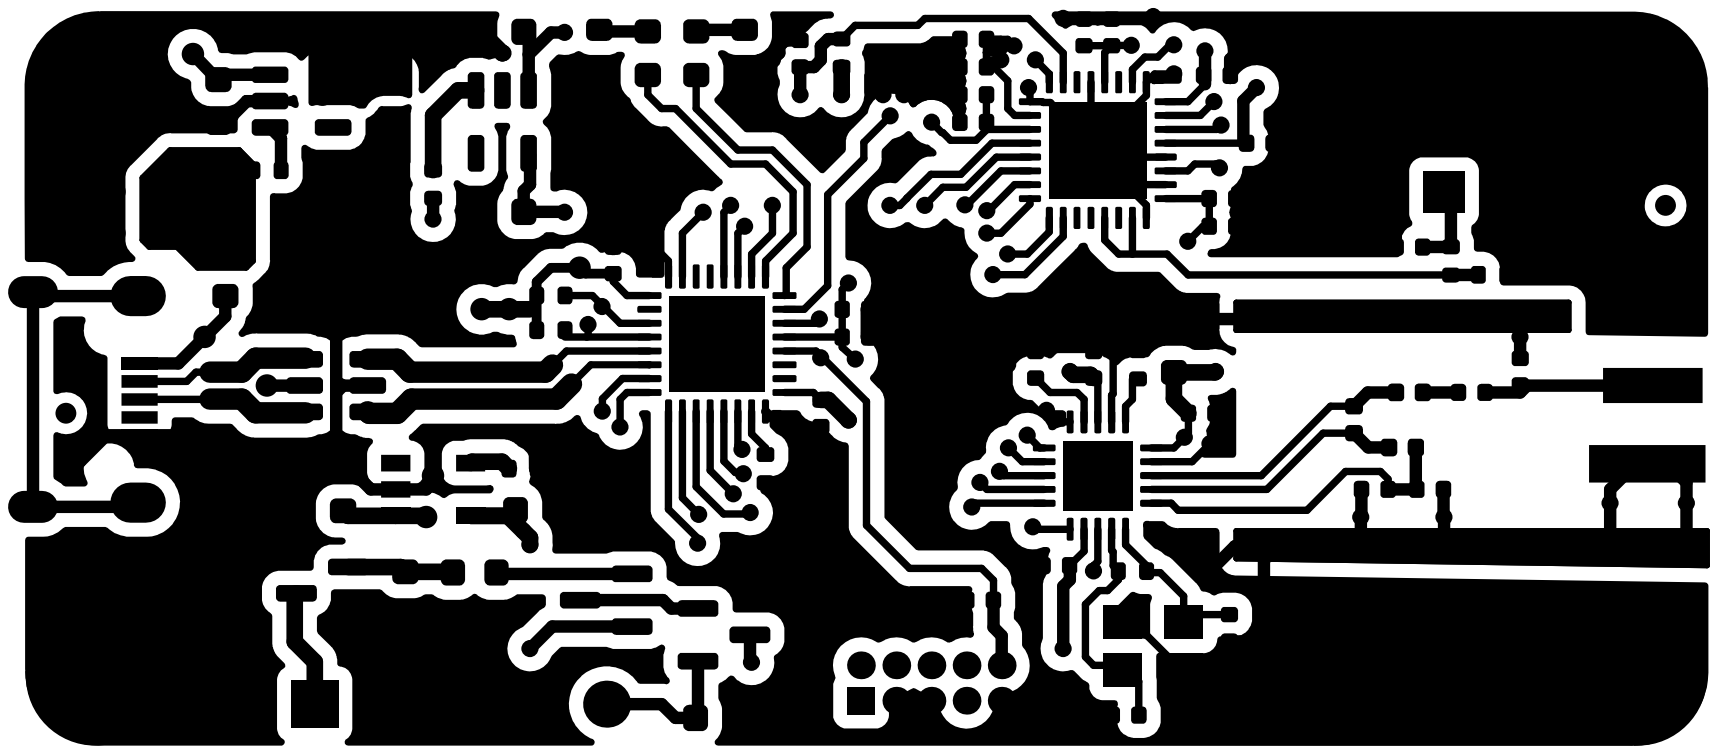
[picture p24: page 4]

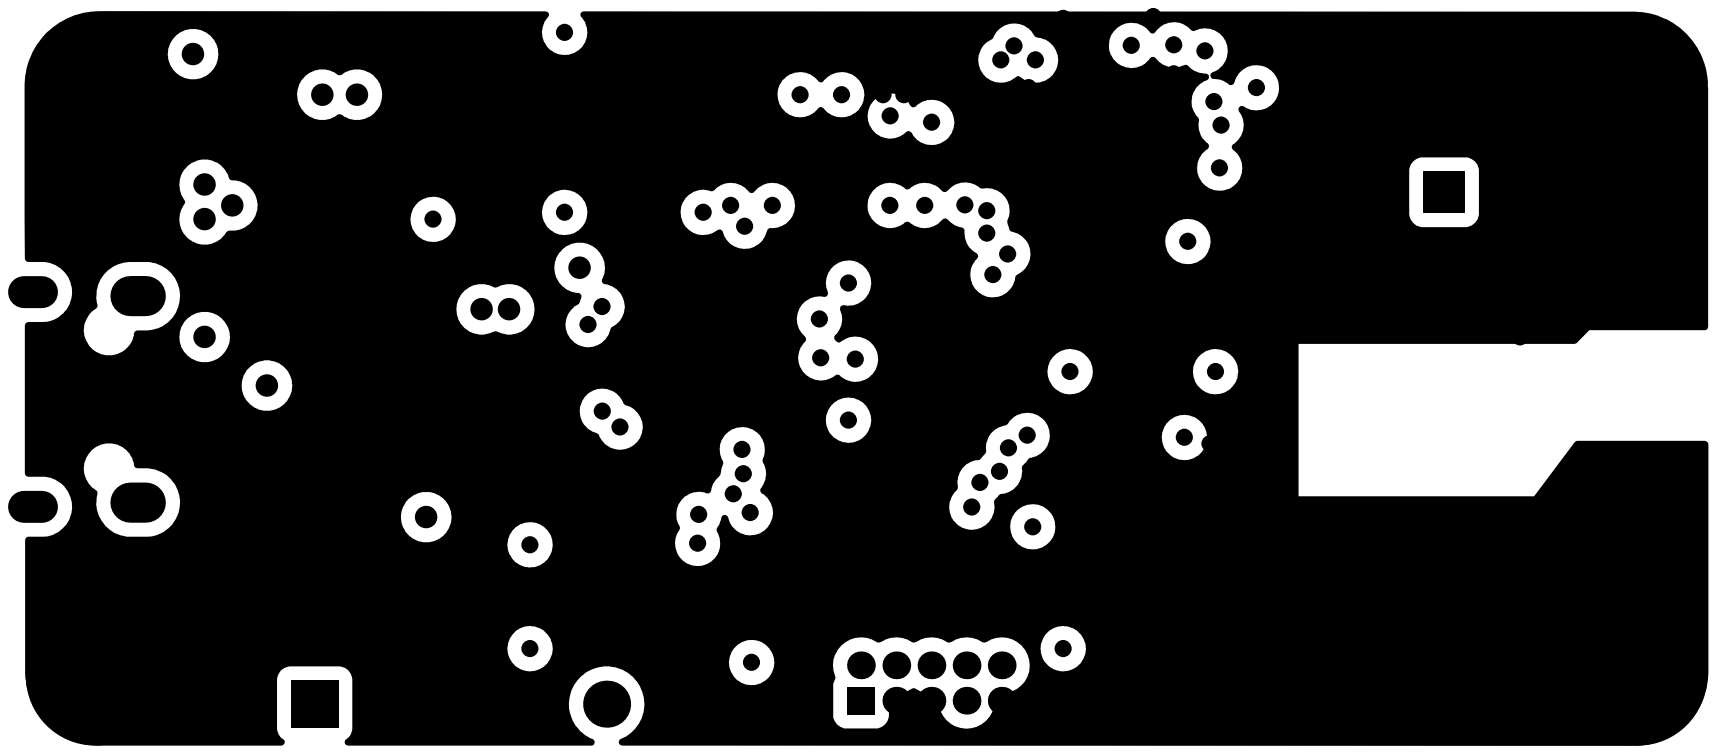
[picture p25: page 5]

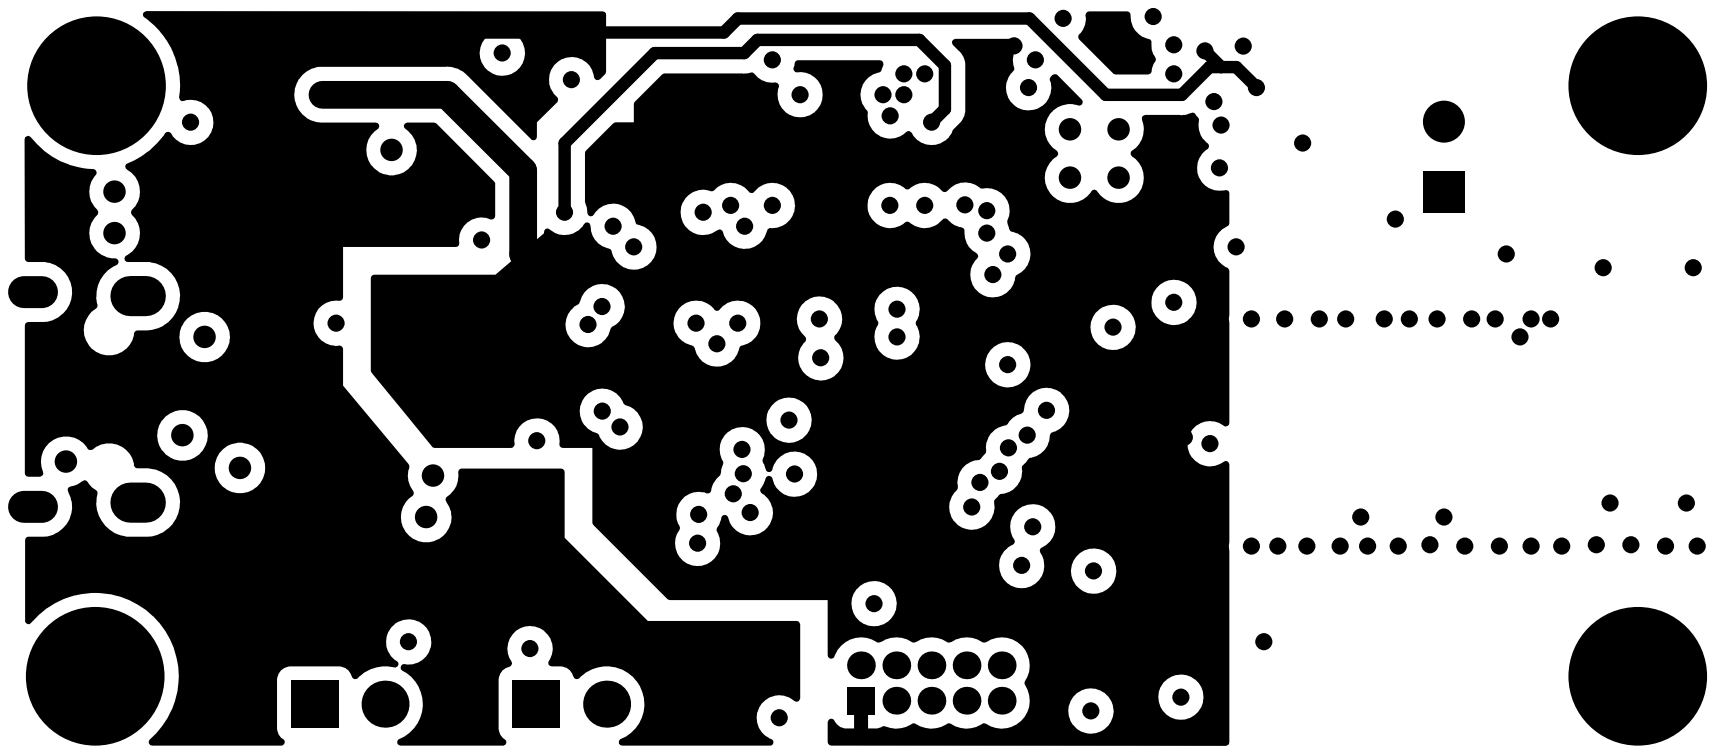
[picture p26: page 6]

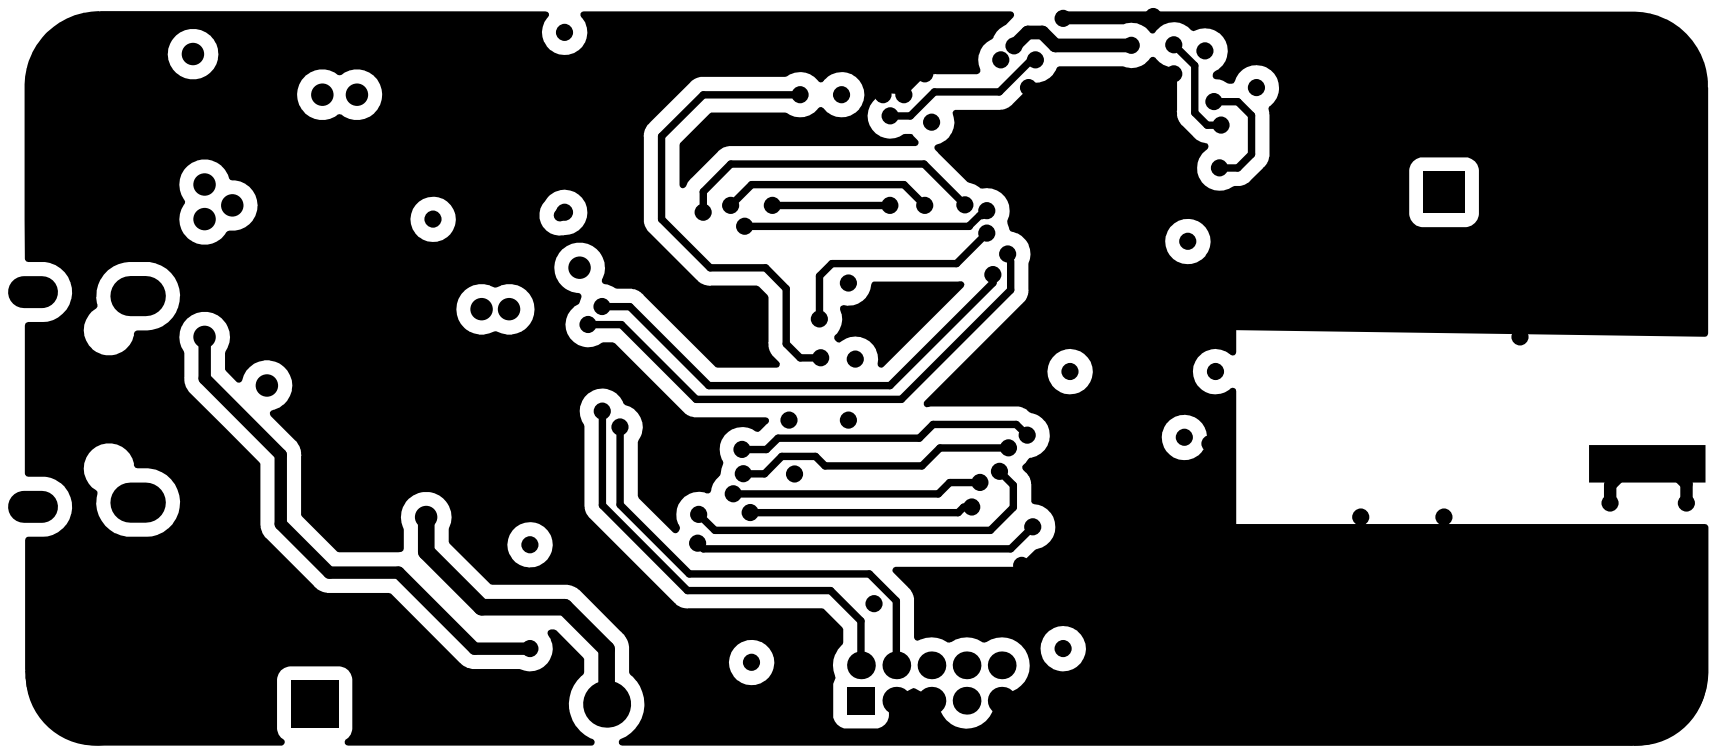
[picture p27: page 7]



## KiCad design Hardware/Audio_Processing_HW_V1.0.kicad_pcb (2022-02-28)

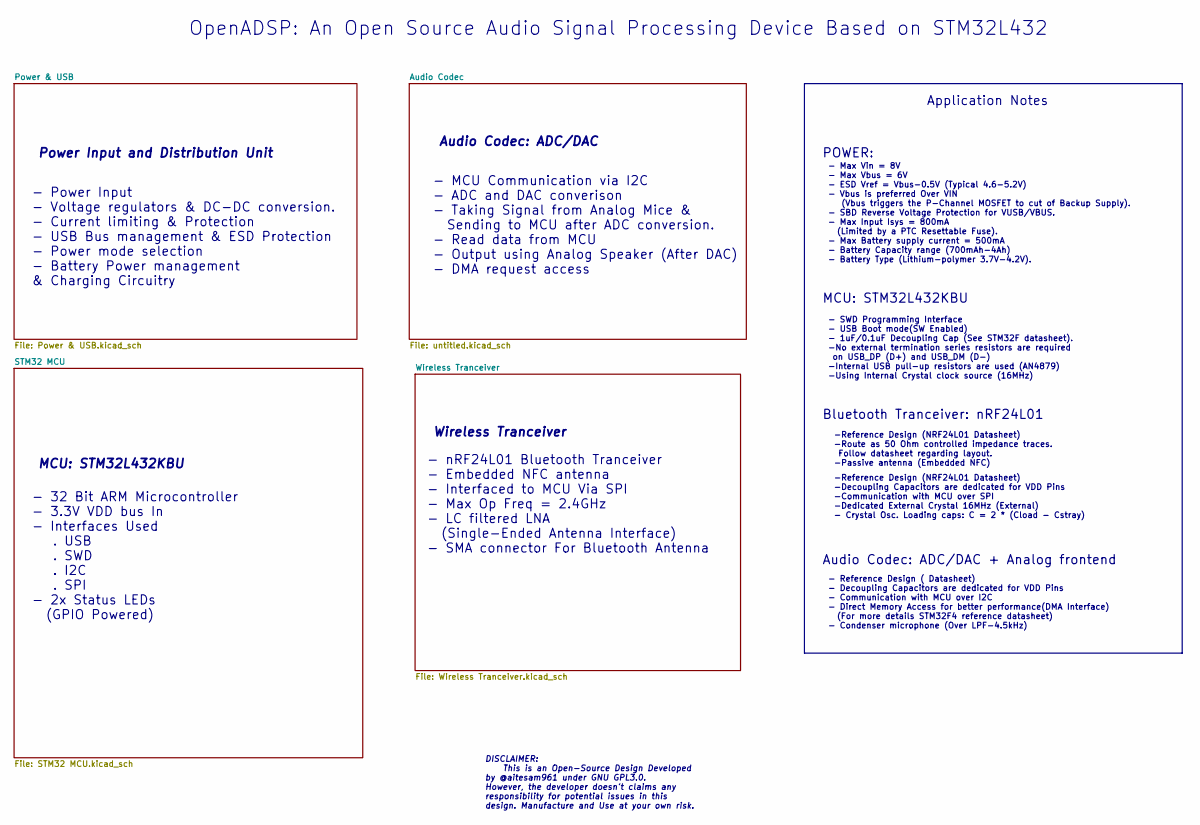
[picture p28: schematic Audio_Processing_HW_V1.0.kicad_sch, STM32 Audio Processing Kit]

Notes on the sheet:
OpenADSP: An Open Source Audio Signal Processing Device Based on STM32L432
Audio Codec: ADC/DAC
MCU: STM32L432KBU
- MCU Communication via I2C - ADC and DAC converison - Taking Signal from Analog Mice & Sending to MCU after ADC conversion. - Read data from MCU - Output using Analog Speaker (After DAC) - DMA request access
- nRF24L01 Bluetooth Tranceiver - Embedded NFC antenna - Interfaced to MCU Via SPI - Max Op Freq = 2.4GHz - LC filtered LNA (Single-Ended Antenna Interface) - SMA connector For Bluetooth Antenna
MCU: STM32L432KBU
POWER:
- Reference Design ( Datasheet) - Decoupling Capacitors are dedicated for VDD Pins - Communication with MCU over I2C - Direct Memory Access for better performance(DMA Interface) (For more details STM32F4 reference datasheet) - Condenser microphone (Over LPF-4.5kHz)
- Power Input - Voltage regulators & DC-DC conversion. - Current limiting & Protection - USB Bus management & ESD Protection - Power mode selection - Battery Power management & Charging Circuitry
-Reference Design (NRF24L01 Datasheet) -Decoupling Capacitors are dedicated for VDD Pins -Communication with MCU over SPI -Dedicated External Crystal 16MHz (External) - Crystal Osc. Loading caps: C = 2 * (Cload - Cstray)
Power Input and Distribution Unit
- 32 Bit ARM Microcontroller - 3.3V VDD bus In - Interfaces Used . USB . SWD . I2C . SPI - 2x Status LEDs (GPIO Powered)
Application Notes
- Max Vin = 8V - Max Vbus = 6V - ESD Vref = Vbus-0.5V (Typical 4.6-5.2V) - Vbus is preferred Over VIN (Vbus triggers the P-Channel MOSFET to cut of Backup Supply). - SBD Reverse Voltage Protection for VUSB/VBUS. - Max Input Isys = 800mA (Limited by a PTC Resettable Fuse). - Max Battery supply curre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
Audio Codec: ADC/DAC + Analog frontend
-Reference Design (NRF24L01 Datasheet) -Route as 50 Ohm controlled impedance traces. Follow datasheet regarding layout. -Passive antenna (Embedded NFC)
Bluetooth Tranceiver: nRF24L01
- SWD Programming Interface - USB Boot mode(SW Enabled) - 1uF/0.1uF Decoupling Cap (See STM32F datasheet). -No external termination series resistors are required on USB_DP (D+) and USB_DM (D-) -Internal USB pull-up resistors are used (AN4879) -Using Internal Crystal clock source (16MHz)
Wireless Tranceiver
DISCLAIMER: This is an Open-Source Design Developed by @aitesam961 under GNU GPL3.0. However, the developer doesn't claims any responsibility for potential issues in this design. Manufacture and Use at your own risk.

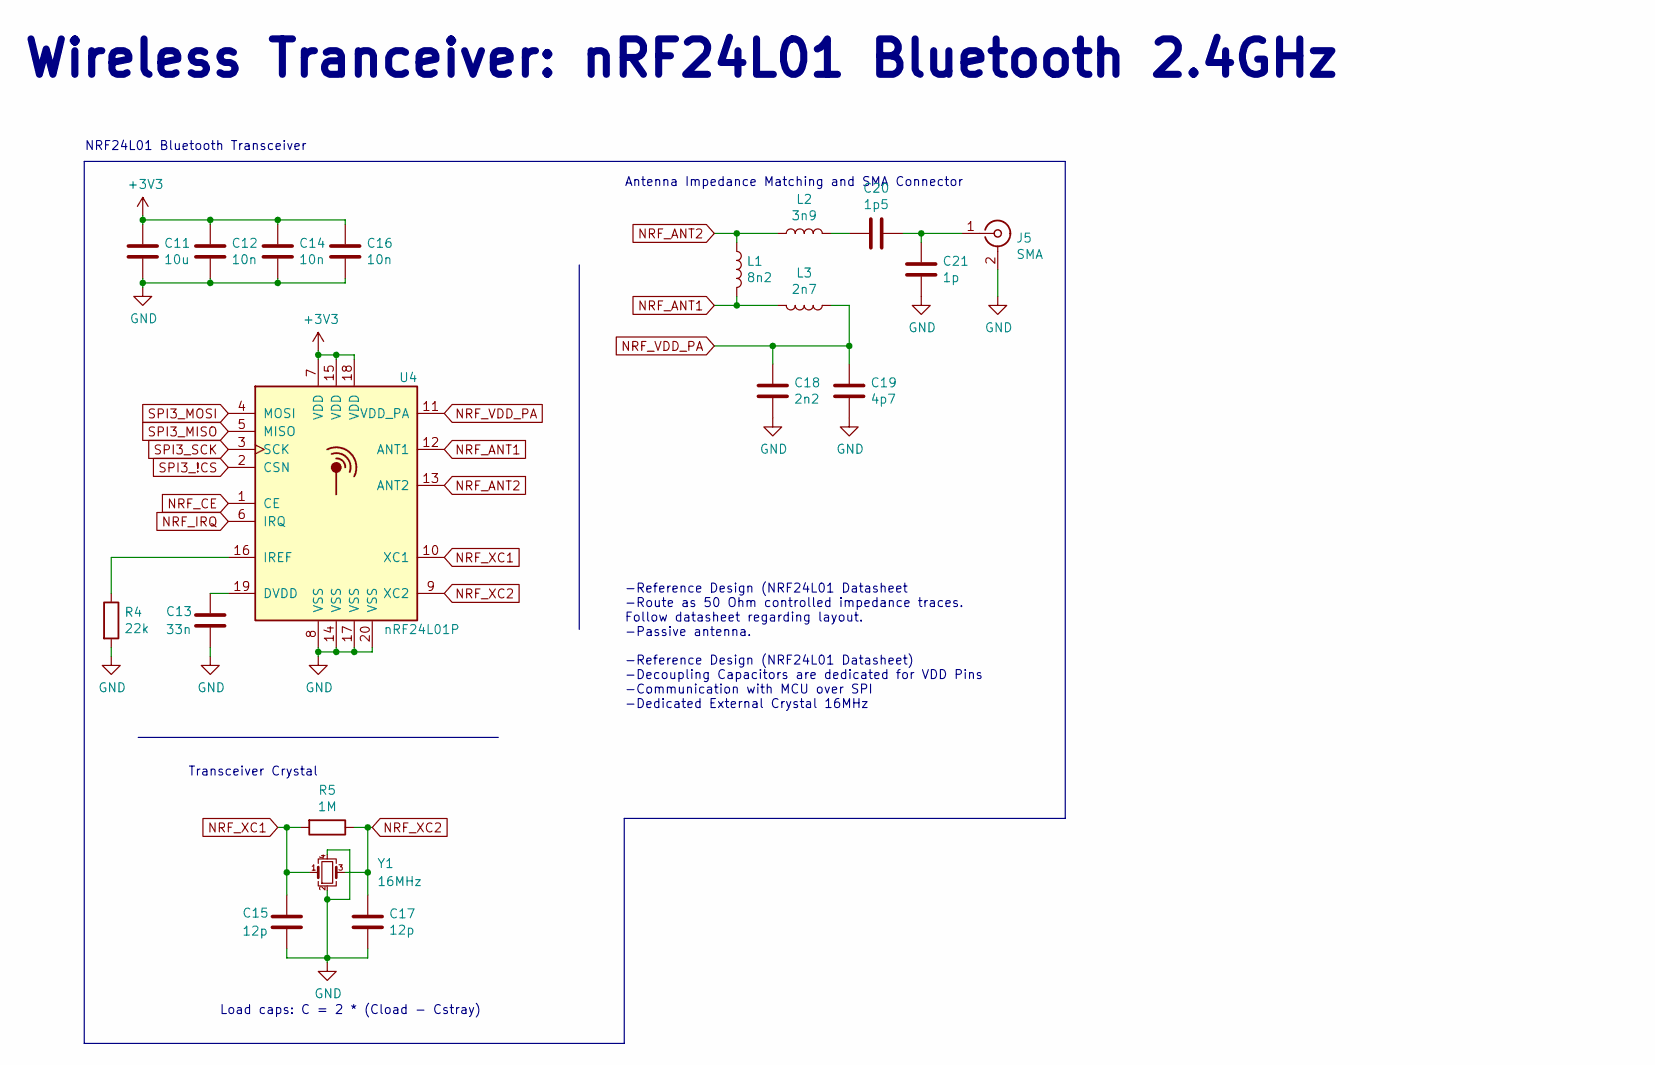
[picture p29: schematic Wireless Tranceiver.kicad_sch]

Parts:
C11: 10u; C_0603_1608Metric
C12, C14, C16: 10n; C_0402_1005Metric
C13: 33n; C_0402_1005Metric
C15, C17: 12p; C_0402_1005Metric
C18: 2n2; C_0402_1005Metric
C19: 4p7; C_0402_1005Metric
C20: 1p5; C_0402_1005Metric
C21: 1p; C_0402_1005Metric
J5: SMA; SMA_Samtec_SMA-J-P-X-ST-EM1_EdgeMount
L1: 8n2; L_0402_1005Metric
L2: 3n9; L_0402_1005Metric
L3: 2n7; L_0402_1005Metric
R4: 22k; R_0402_1005Metric
R5: 1M; R_0402_1005Metric
U4: nRF24L01P; QFN-20-1EP_4x4mm_P0.5mm_EP2.5x2.5mm
Y1: 16MHz; Crystal_SMD_3225-4Pin_3.2x2.5mm

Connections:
+3V3: C11.1, C12.1, C14.1, C16.1, U4.7 (VDD), U4.15 (VDD), U4.18 (VDD); also elsewhere on the board
GND: C11.2, C12.2, C13.2, C14.2, C15.2, C16.2, C17.2, C18.1, C19.1, C21.1, J5.2 (Ext), R4.2, U4.8 (VSS), U4.14 (VSS), U4.17 (VSS), U4.20 (VSS), Y1.2, Y1.4; also elsewhere on the board
NRF_ANT1: L1.2, L3.2, U4.12 (ANT1)
NRF_ANT2: L1.1, L2.1, U4.13 (ANT2)
NRF_CE: U4.1 (CE); also elsewhere on the board
NRF_IRQ: U4.6 (IRQ); also elsewhere on the board
NRF_VDD_PA: C18.2, C19.2, L3.1, U4.11 (VDD_PA)
NRF_XC1: C15.1, R5.2, U4.10 (XC1), Y1.1
NRF_XC2: C17.1, R5.1, U4.9 (XC2), Y1.3
unnamed: C13.1, U4.19 (DVDD)
unnamed: C20.1, C21.2, J5.1 (In)
unnamed: C20.2, L2.2
unnamed: R4.1, U4.16 (IREF)
SPI3_!CS: U4.2 (CSN); also elsewhere on the board
SPI3_MISO: U4.5 (MISO); also elsewhere on the board
SPI3_MOSI: U4.4 (MOSI); also elsewhere on the board
SPI3_SCK: U4.3 (SCK); also elsewhere on the board

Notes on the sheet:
NRF24L01 Bluetooth Transceiver
-Reference Design (NRF24L01 Datasheet) -Decoupling Capacitors are dedicated for VDD Pins -Communication with MCU over SPI -Dedicated External Crystal 16MHz
Transceiver Crystal
Antenna Impedance Matching and SMA Connector
Load caps: C = 2 * (Cload - Cstray)
-Reference Design (NRF24L01 Datasheet -Route as 50 Ohm controlled impedance traces. Follow datasheet regarding layout. -Passive antenna.
Wireless Tranceiver: nRF24L01 Bluetooth 2.4GHz

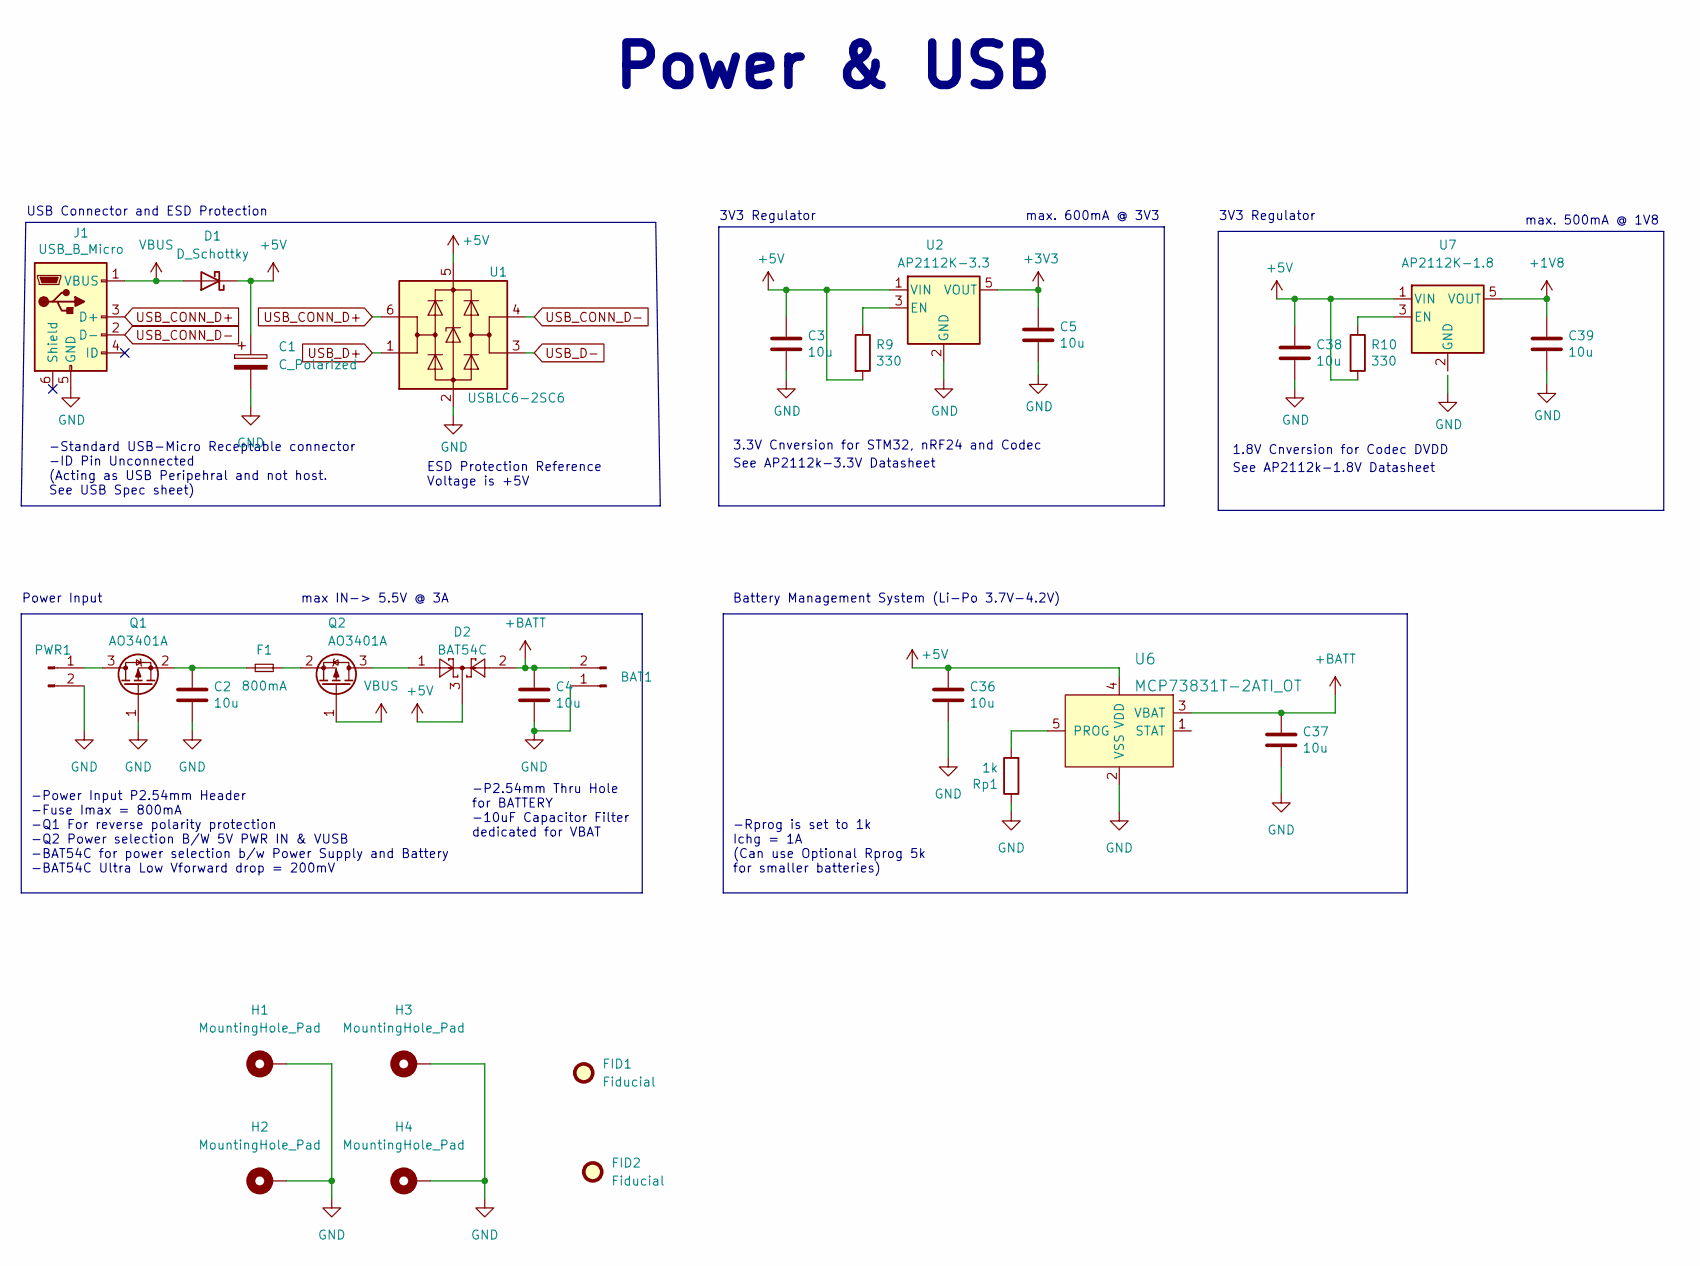
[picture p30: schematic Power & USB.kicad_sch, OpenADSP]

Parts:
BAT1: Conn_01x02_Male; PinHeader_1x02_P2.54mm_Vertical
C1: C_Polarized; CP_EIA-3528-12_Kemet-T
C2, C3, C4, C5, C36, C37, C38, C39: 10u; C_0603_1608Metric
D1: D_Schottky; D_0603_1608Metric
D2: BAT54C; SOT-23
F1: 800mA; Fuse_0603_1608Metric
FID1, FID2: Fiducial; Fiducial_0.75mm_Mask1.5mm
H1, H2, H3, H4: MountingHole_Pad; MountingHole_2.5mm_Pad_Via
J1: USB_B_Micro; USB_Micro-B_Wuerth_629105150521
PWR1: Conn_01x02_Male; PinHeader_1x02_P2.54mm_Vertical
Q1, Q2: AO3401A; SOT-23
R9, R10: 330; R_0402_1005Metric
Rp1: 1k; R_0402_1005Metric
U1: USBLC6-2SC6; SOT-23-6
U2: AP2112K-3.3; SOT-23-5
U6: MCP73831T-2ATI_OT; SOT-753; MPN MCP73831T-2ATI/OT; Digi-Key_PN MCP73831T-2ATI/OTCT-ND
U7: AP2112K-1.8; SOT-23-5

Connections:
+1V8: C39.1, U7.5 (VOUT); also elsewhere on the board
+3V3: C5.1, U2.5 (VOUT); also elsewhere on the board
+5V: C1.1, C3.1, C36.1, C38.1, D1.1 (K), D2.3, R9.2, R10.2, U1.5 (VBUS), U2.1 (VIN), U6.4 (VDD), U7.1 (VIN); also elsewhere on the board
+BATT: BAT1.2, C4.1, C37.1, D2.2, U6.3 (VBAT)
GND: BAT1.1, C1.2, C2.2, C3.2, C4.2, C5.2, C36.2, C37.2, C38.2, C39.2, H1.1, H2.1, H3.1, H4.1, J1.5 (GND), PWR1.2, Q1.1 (G), Rp1.1, U1.2 (GND), U2.2 (GND), U6.2 (VSS); also elsewhere on the board
unnamed: C2.1, F1.1, Q1.2 (S)
unnamed: D2.1, Q2.3 (D)
unnamed: F1.2, Q2.2 (S)
unnamed: PWR1.1, Q1.3 (D)
unnamed: R10.1, U7.3 (EN)
unnamed: Rp1.2, U6.5 (PROG)
unnamed: R9.1, U2.3 (EN)
USB_CONN_D+: J1.3 (D+), U1.6 (I/O1)
USB_CONN_D-: J1.2 (D-), U1.4 (I/O2)
USB_D+: U1.1 (I/O1); also elsewhere on the board
USB_D-: U1.3 (I/O2); also elsewhere on the board
VBUS: D1.2 (A), J1.1 (VBUS), Q2.1 (G)

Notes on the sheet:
1.8V Cnversion for Codec DVDD
-Rprog is set to 1k Ichg = 1A (Can use Optional Rprog 5k for smaller batteries)
-P2.54mm Thru Hole for BATTERY -10uF Capacitor Filter dedicated for VBAT
-Standard USB-Micro Receptable connector -ID Pin Unconnected (Acting as USB Peripehral and not host. See USB Spec sheet)
Power & USB
3V3 Regulator
max. 500mA @ 1V8
Battery Management System (Li-Po 3.7V-4.2V)
max. 600mA @ 3V3
ESD Protection Reference Voltage is +5V
See AP2112k-1.8V Datasheet
3.3V Cnversion for STM32, nRF24 and Codec
USB Connector and ESD Protection
Power Input
See AP2112k-3.3V Datasheet
-Power Input P2.54mm Header -Fuse Imax = 800mA -Q1 For reverse polarity protection -Q2 Power selection B/W 5V PWR IN & VUSB -BAT54C for power selection b/w Power Supply and Battery -BAT54C Ultra Low Vforward drop = 200mV
max IN-> 5.5V @ 3A

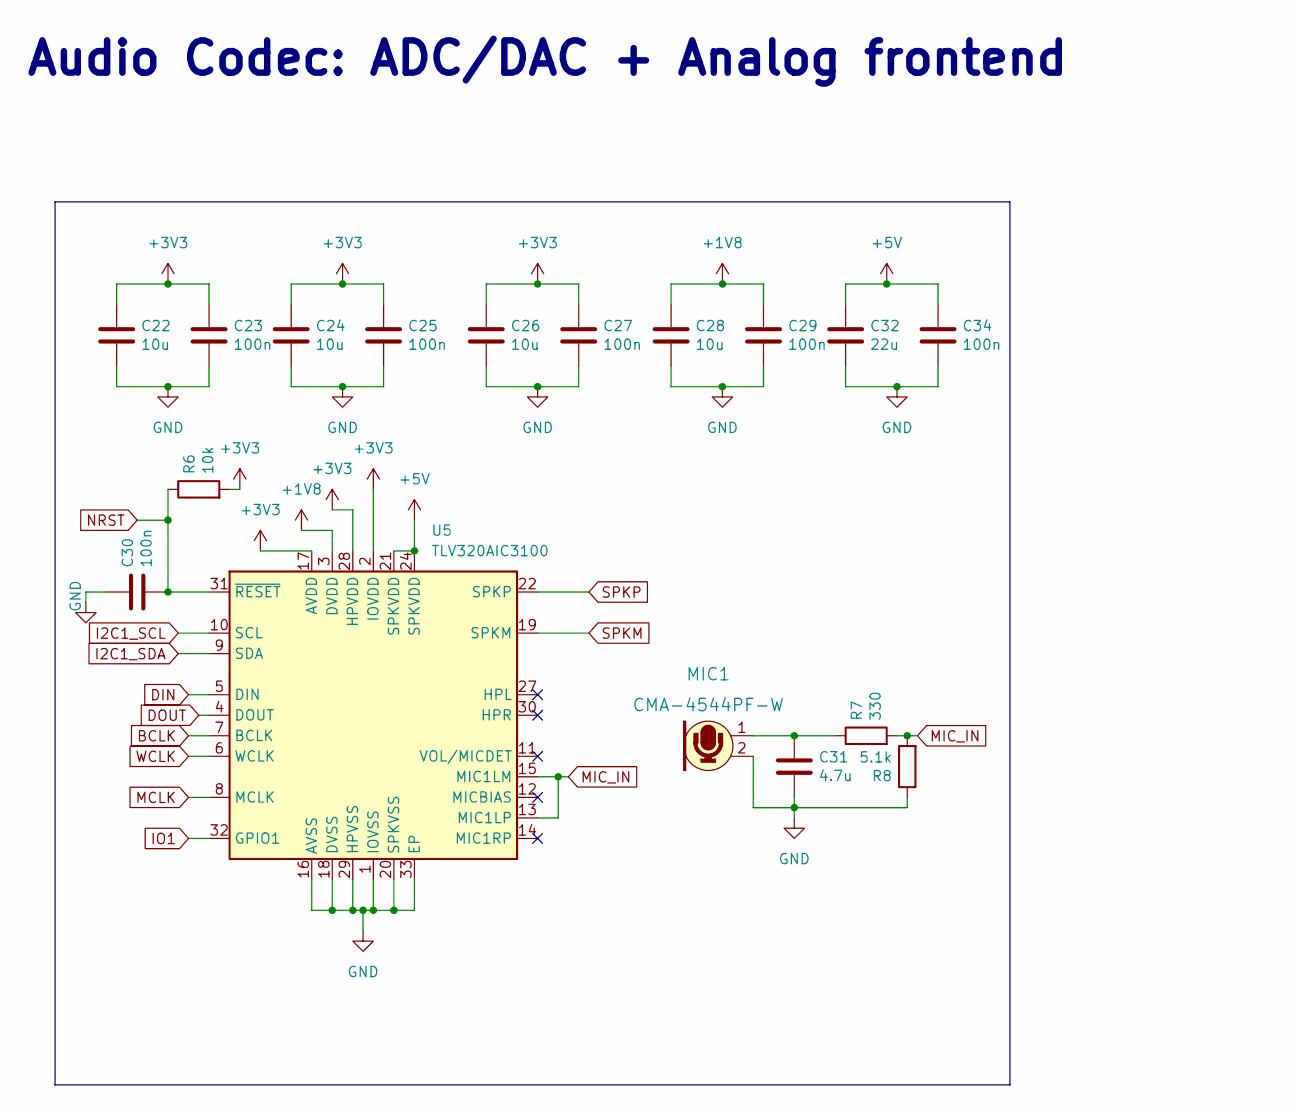
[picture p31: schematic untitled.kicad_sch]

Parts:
C22, C24, C26, C28: 10u; C_0402_1005Metric
C23, C25, C27, C29, C30, C34: 100n; C_0402_1005Metric
C31: 4.7u; C_0402_1005Metric
C32: 22u; C_0402_1005Metric
MIC1: CMA-4544PF-W; Mic_CMA-4544PF-W; MPN CMA-4544PF-W; Digi-Key_PN 102-1721-ND
R6: 10k; R_0402_1005Metric
R7: 330; R_0402_1005Metric
R8: 5.1k; R_0402_1005Metric
U5: TLV320AIC3100; VQFN-32-1EP_5x5mm_P0.5mm_EP3.5x3.5mm

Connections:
+1V8: C28.1, C29.1, U5.3 (DVDD); also elsewhere on the board
+3V3: C22.1, C23.1, C24.1, C25.1, C26.1, C27.1, R6.2, U5.2 (IOVDD), U5.17 (AVDD), U5.28 (HPVDD); also elsewhere on the board
+5V: C32.1, C34.1, U5.21 (SPKVDD), U5.24 (SPKVDD); also elsewhere on the board
BCLK: U5.7 (BCLK); also elsewhere on the board
DIN: U5.5 (DIN); also elsewhere on the board
DOUT: U5.4 (DOUT); also elsewhere on the board
GND: C22.2, C23.2, C24.2, C25.2, C26.2, C27.2, C28.2, C29.2, C30.1, C31.2, C32.2, C34.2, MIC1.2, R8.1, U5.1 (IOVSS), U5.16 (AVSS), U5.18 (DVSS), U5.20 (SPKVSS), U5.25 (SPKVSS), U5.29 (HPVSS), U5.33 (EP); also elsewhere on the board
I2C1_SCL: U5.10 (SCL); also elsewhere on the board
I2C1_SDA: U5.9 (SDA); also elsewhere on the board
IO1: U5.32 (GPIO1); also elsewhere on the board
MCLK: U5.8 (MCLK); also elsewhere on the board
MIC_IN: R7.2, R8.2, U5.13 (MIC1LP), U5.15 (MIC1LM)
NRST: C30.2, R6.1, U5.31 (~RESET); also elsewhere on the board
unnamed: C31.1, MIC1.1, R7.1
SPKM: U5.19 (SPKM), U5.23 (SPKM)
SPKP: U5.22 (SPKP), U5.26 (SPKP)
WCLK: U5.6 (WCLK); also elsewhere on the board

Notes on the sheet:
Audio Codec: ADC/DAC + Analog frontend

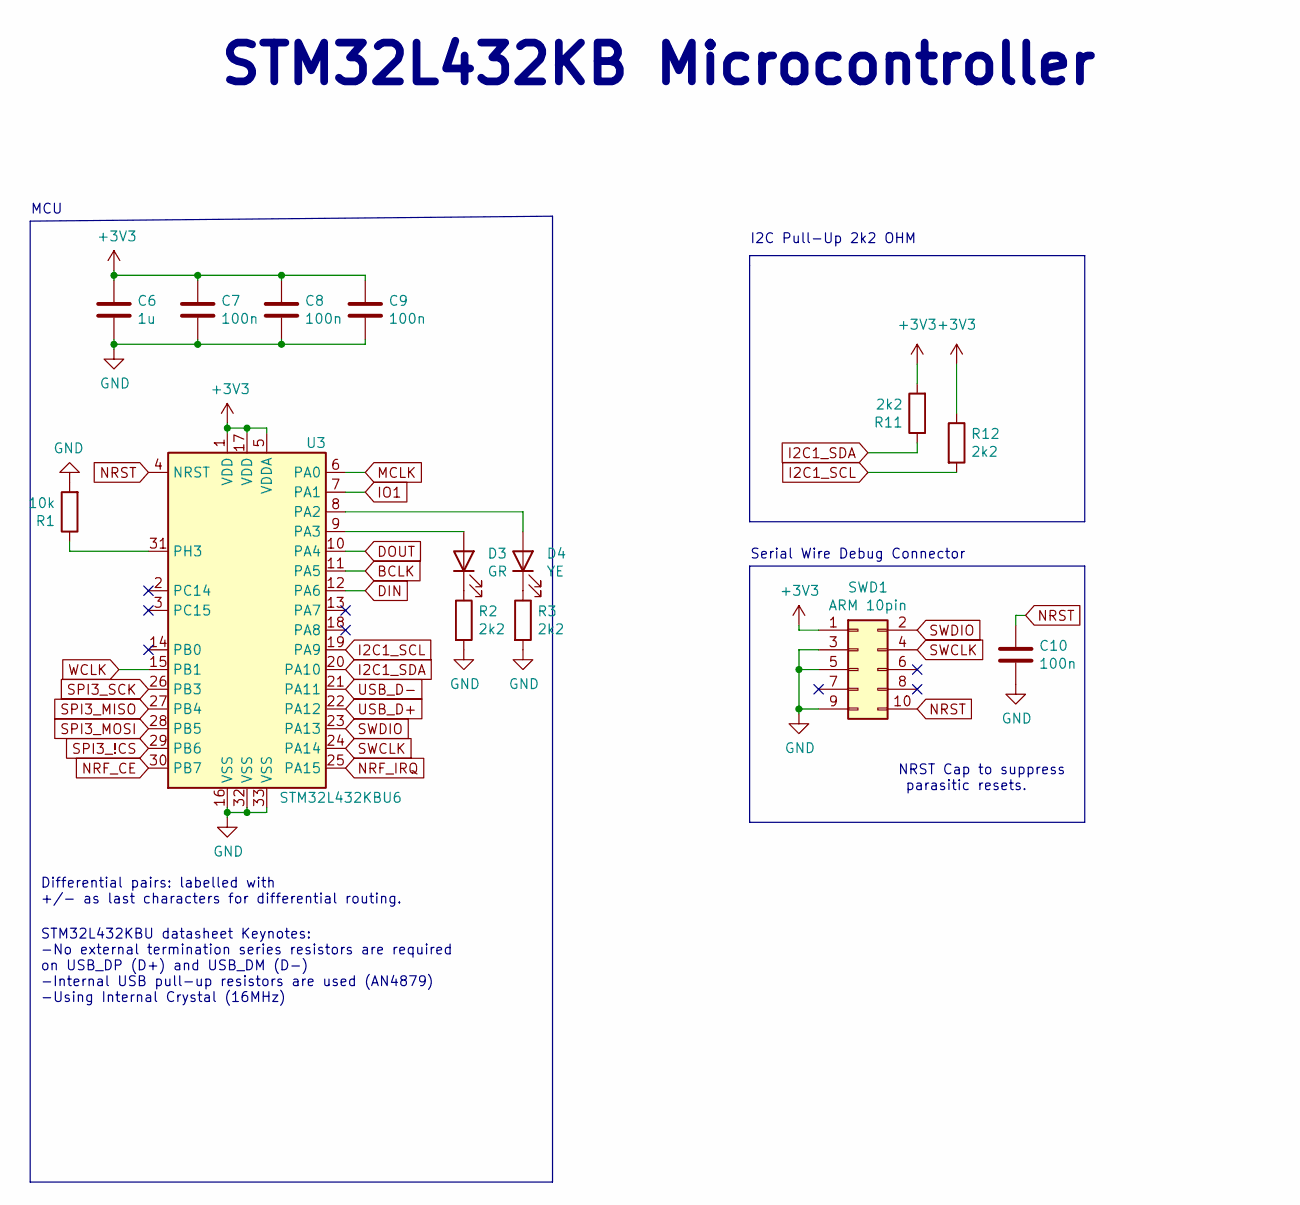
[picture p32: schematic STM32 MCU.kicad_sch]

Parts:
C6: 1u; C_0402_1005Metric
C7, C8, C9, C10: 100n; C_0402_1005Metric
D3: GR; LED_0603_1608Metric
D4: YE; LED_0603_1608Metric
R1: 10k; R_0402_1005Metric
R2, R3: 2k2; R_0603_1608Metric
R11, R12: 2k2; R_0402_1005Metric
SWD1: ARM 10pin; PinHeader_2x05_P1.27mm_Vertical
U3: STM32L432KBU6; QFN-32-1EP_5x5mm_P0.5mm_EP3.45x3.45mm

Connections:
+3V3: C6.1, C7.1, C8.1, C9.1, R11.2, R12.1, SWD1.1, U3.1 (VDD), U3.5 (VDDA), U3.17 (VDD); also elsewhere on the board
BCLK: U3.11 (PA5); also elsewhere on the board
DIN: U3.12 (PA6); also elsewhere on the board
DOUT: U3.10 (PA4); also elsewhere on the board
GND: C6.2, C7.2, C8.2, C9.2, C10.2, R1.2, R2.2, R3.2, SWD1.3, SWD1.5, SWD1.9, U3.16 (VSS), U3.32 (VSS), U3.33 (VSS); also elsewhere on the board
I2C1_SCL: R12.2, U3.19 (PA9); also elsewhere on the board
I2C1_SDA: R11.1, U3.20 (PA10); also elsewhere on the board
IO1: U3.7 (PA1); also elsewhere on the board
MCLK: U3.6 (PA0); also elsewhere on the board
NRF_CE: U3.30 (PB7); also elsewhere on the board
NRF_IRQ: U3.25 (PA15); also elsewhere on the board
NRST: C10.1, SWD1.10, U3.4 (NRST); also elsewhere on the board
unnamed: D3.1 (K), R2.1
unnamed: D3.2 (A), U3.9 (PA3)
unnamed: D4.1 (K), R3.1
unnamed: D4.2 (A), U3.8 (PA2)
unnamed: R1.1, U3.31 (PH3)
SPI3_!CS: U3.29 (PB6); also elsewhere on the board
SPI3_MISO: U3.27 (PB4); also elsewhere on the board
SPI3_MOSI: U3.28 (PB5); also elsewhere on the board
SPI3_SCK: U3.26 (PB3); also elsewhere on the board
SWCLK: SWD1.4, U3.24 (PA14)
SWDIO: SWD1.2, U3.23 (PA13)
USB_D+: U3.22 (PA12); also elsewhere on the board
USB_D-: U3.21 (PA11); also elsewhere on the board
WCLK: U3.15 (PB1); also elsewhere on the board

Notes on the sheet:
STM32L432KBU datasheet Keynotes: -No external termination series resistors are required on USB_DP (D+) and USB_DM (D-) -Internal USB pull-up resistors are used (AN4879) -Using Internal Crystal (16MHz)
Serial Wire Debug Connector
NRST Cap to suppress parasitic resets.
Differential pairs: labelled with +/- as last characters for differential routing.
STM32L432KB Microcontroller
MCU
I2C Pull-Up 2k2 OHM

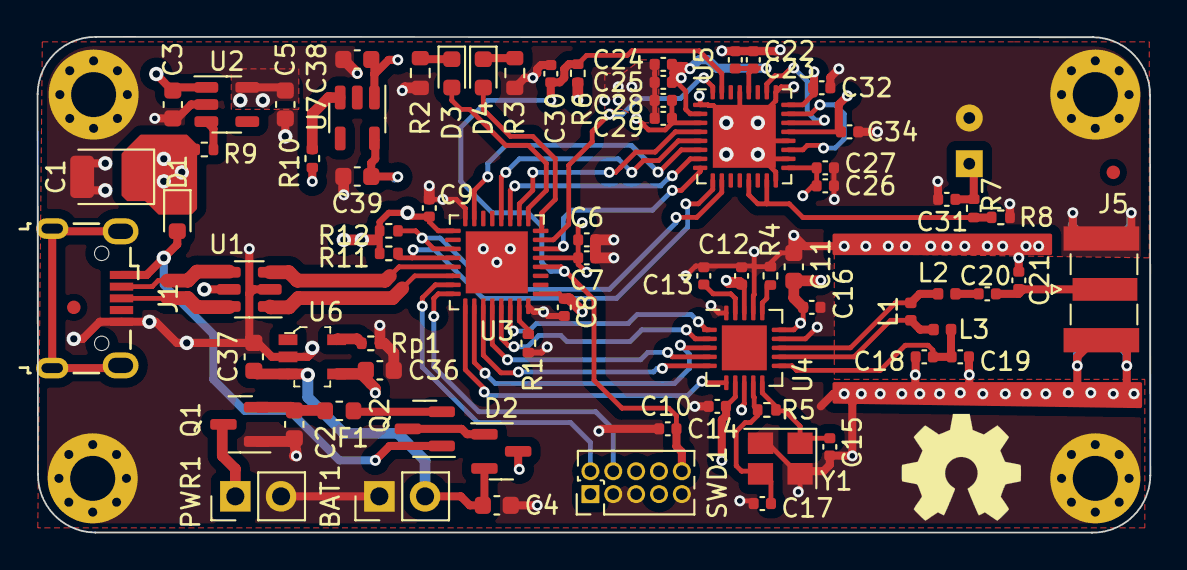
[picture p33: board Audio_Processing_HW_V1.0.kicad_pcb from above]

Board: 4 copper layers, 61.8 x 27.5 mm, 80 parts (1 on the bottom side), 52 nets.

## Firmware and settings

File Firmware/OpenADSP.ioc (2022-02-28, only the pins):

Mcu.UserName=STM32L432KBUx
PA0.Signal=RCC_CK_IN
PA1.Signal=SPI1_SCK
PA10.Signal=I2C1_SDA
PA11.Signal=USB_DM
PA12.Signal=USB_DP
PA2.Signal=S_TIM2_CH3
PA4.Signal=GPIO_Output
PA5.Signal=GPIO_Output
PA6.Signal=GPIO_Input
PA9.Signal=I2C1_SCL
PB1.Signal=GPIO_Output
PB5.Signal=SPI1_MOSI
PB6.Signal=GPIO_Output
PB7.Signal=GPIO_Output
PH3-BOOT0.Signal=GPIO_Output

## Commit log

2022-02-28 Uploaded KiCad Project Source Files
    A Complete set of source files
    KiCad V6.0
    [Analog Filters.kicad_sch, Audio_Processing_HW_V1.0.kicad_pcb, Audio_Processing_HW_V1.0.kicad_sch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]
2022-02-28 Uploaded STM32CubeIDE Project Source Files
2022-03-01 OpenADSP
    OpenADSP is a Digital Signal Processing device designed to process and transmit Audio signals over wired & wireless communication protocols

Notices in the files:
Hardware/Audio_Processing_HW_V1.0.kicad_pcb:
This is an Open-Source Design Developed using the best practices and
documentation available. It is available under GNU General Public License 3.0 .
